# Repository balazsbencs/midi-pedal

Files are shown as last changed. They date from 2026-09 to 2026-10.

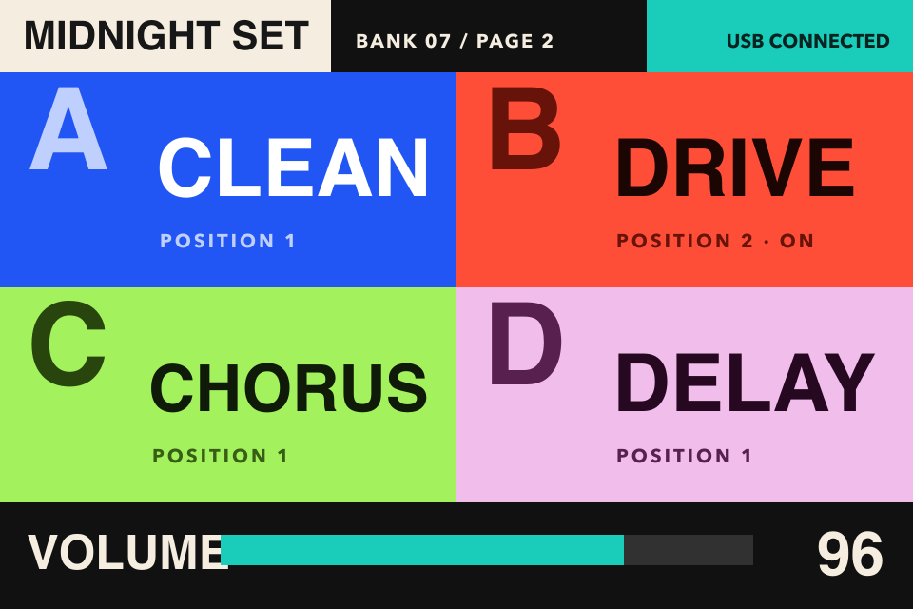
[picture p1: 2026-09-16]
docs/ui-concepts/05-gig-poster.png

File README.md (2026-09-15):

# MIDI Pedal

An open-source four-switch MIDI foot controller built around a Raspberry Pi Pico 2. It follows the focused live interaction model of the Morningstar MC4 Pro while keeping the hardware, protocol, and editor approachable for builders.

## Project status

This repository is work in progress. The approved design and implementation
roadmap are complete; firmware, editor, carrier PCB, enclosure files, and
qualification artifacts are being built in phases. Do not use an unqualified
revision on stage.

The v1 boundary is four normally-open footswitches, an ST7796S 480×320 display, TRS Type-A MIDI OUT, class-compliant USB-MIDI, one expression input, and two isolated normally-open relay contacts. There is no MIDI input, wireless feature, touch input, auxiliary control, USB host mode, or on-device setup menu.

## Start here

```bash
git clone --recurse-submodules git@github.com:balazsbencs/midi-pedal.git
cd midi-pedal
corepack enable
pnpm install --frozen-lockfile
pnpm check
```

Read the [approved design](docs/superpowers/specs/2026-09-01-midi-controller-pedal-design.md) and [implementation roadmap](docs/superpowers/plans/2026-09-01-midi-controller-pedal-implementation-plan.md) before building hardware.

The portable configuration and USB frame contracts are documented in [docs/protocol.md](docs/protocol.md). The phase plans define the exact firmware, editor, hardware, and release gates while implementation is in progress.

## Repository map

- `packages/protocol/` — shared JSON schema, binary image, and USB frame contracts.
- `firmware/` — Pico 2 C++20 firmware and native tests.
- `editor/` — static React editor for desktop Chromium browsers.
- `hardware/` — KiCad carrier PCB, enclosure drawings, and fabrication outputs.
- `docs/` — build, flashing, hosting, assembly, protocol, troubleshooting, and acceptance guides.
- `tools/` — validation, HIL, and release tooling.

Detailed guides: [building](docs/building.md), [flashing](docs/flashing.md), [editor hosting](docs/editor-hosting.md), [hardware assembly](docs/hardware-assembly.md), [protocol](docs/protocol.md), [troubleshooting](docs/troubleshooting.md), [releasing](docs/releasing.md), and [contributing](CONTRIBUTING.md).

## Build and flash

Use the verified [build guide](docs/building.md) and [flashing guide](docs/flashing.md). Power hardware only after reading the 9 V center-negative polarity and relay-contact warnings in the [assembly guide](docs/hardware-assembly.md).

The editor is available at
[balazsbencs.github.io/midi-pedal](https://balazsbencs.github.io/midi-pedal/)
and is automatically deployed from `main`; see
[editor hosting](docs/editor-hosting.md).
The browser connects directly to the pedal over WebSerial and never requires a
project account or backend. Configuration is intentionally prepared off-stage;
the pedal has no touch setup or wireless feature.

## Release downloads

Every push to `main` runs the release pipeline. It calculates the next SemVer
from conventional commits, builds the firmware, and publishes a GitHub Release
with the generated changelog, checksums, and downloadable `firmware.uf2` image.
Use the [GitHub Releases](https://github.com/balazsbencs/midi-pedal/releases)
page and follow the included `flashing.md` guide (or the checked-in
[flashing guide](docs/flashing.md)) before installing an image.

## License

The repository uses MIT for software, CERN-OHL-S-2.0 for hardware design, and
CC-BY-SA-4.0 for documentation. See [LICENSE](LICENSE) and the notices under
`LICENSES/` as they land.

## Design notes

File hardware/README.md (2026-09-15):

# Carrier hardware (work in progress)

The reference build uses a socketed Raspberry Pi Pico 2 on a two-layer carrier
inside a measured Hammond 1590DD-style enclosure. The electrical intent is
captured in the approved design specification and the bench-review sheets in
this directory. Production footprints and fabrication exports must not be
released until they have been checked against the actual display, jacks,
switches, relays, and enclosure.

Current repository artifacts:

- [`pico2-pinout.svg`](pico2-pinout.svg) is the illustrated firmware-to-panel
  wiring reference, including physical Pico 2 header pin numbers.
- `midi-pedal.kicad_pcb` is a safe board-outline/project starting point; it is
  not a routed production board.
- `bench/` contains review sheets for protected power and I/O circuits.
- `mechanical/measured-components.csv` records the measurements still needed
  before cutouts are frozen.
- `validation/` contains evidence tables; unchecked hardware rows are pending.

Never connect an unverified relay contact or external amplifier voltage to a
Pico GPIO. The two relay contacts must remain dry, isolated, and normally open.
Display logic is 3.3 V; verify a breakout's VCC rating before selecting its
3.3 V/5 V supply jumper. The ST7796S backlight is always on and SDO is not
routed.

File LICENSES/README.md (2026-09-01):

# License split

- `MIT.txt`: firmware, editor, protocol, tools, CI, and other software.
- `CERN-OHL-S-2.0.txt`: carrier PCB, schematics, footprints, fabrication, and
  enclosure/mechanical source.
- `CC-BY-SA-4.0.txt`: project documentation, plans, specifications, and
  validation guides.

Third-party code and documentation under `third_party/` retain their upstream
licenses. Each release manifest records the license for public artifacts.

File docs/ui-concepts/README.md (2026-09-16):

# Pedal display UI concepts

These five concepts use only information that the live firmware already exposes, except where noted. Every mockup is drawn at the display's native 480×320 aspect ratio and is intended to survive RGB565 conversion.

## 01 — Chromatic Deck (recommended)

The safest high-quality direction for a live pedal: a stable 2×2 spatial map matching switches A–D, with color used as a strong identity and a full fill for the active toggle state. It remains readable from standing distance and maps cleanly to dirty-region rendering.

Implementation: four fixed quadrant regions, a 42 px status header, and a 44 px expression footer. No new runtime state is required.

## 02 — Analog Console

A physical-instrument look based on rack labels, channel strips, indicator lamps, and a segmented expression meter. It feels like dedicated music hardware rather than a generic app.

Implementation: four fixed columns. Circles and meter segments are simple integer primitives. No image assets or new runtime state are required.

## 03 — Performance Focus

The most recently operated switch becomes the hero while the other three remain visible in a side rail. This has the strongest active-state feedback and the largest preset name.

Implementation: requires adding `activeSwitch` to `LiveView`, updated on switch activation. A switch change redraws the hero and side rail, so it moves more pixels than the fixed-grid concepts.

## 04 — Signal Flow

A vertical chain view that reads like a signal path. The selected preset is a full-width interruption in the chain; inactive choices are quieter but still clear.

Implementation: four horizontal rows and fixed state badges. It uses only current runtime data and makes each row independently redrawable.

## 05 — Gig Poster

The boldest direction: borderless color fields and oversized condensed type. It treats the display like stage graphics, with almost no interface chrome.

Implementation: four fixed quadrant fills plus a footer. This is computationally the simplest concept and has the best fallback behavior if typography is reduced to a 1-bit mask.

## Rendering plan

- Keep the current 480×320 RGB565 framebuffer: 307,200 bytes.
- Store font glyph atlases in flash, not RAM. Convert an open-source condensed display face and a highly legible small face into 4-bit alpha masks at build time. Blend those masks directly into RGB565; this gives visibly smoother type without LVGL.
- Add a small renderer layer for filled rectangles, lines, circles, clipped text, and alpha-mask glyphs. These five concepts need no general widget framework.
- Draw into the existing framebuffer and use the panel's proven full-screen address window. This specific module misplaces partial vertical windows, so correctness takes priority over regional transfer size.
- Hold chip-select active for the frame and stream it four scanlines at a time. MIDI, USB, switch scanning, and watchdog work run between these bounded transfer steps while the controller remains in continuous RAM-write mode.
- At the current 8 MHz SPI clock, a full frame takes about 307 ms of total wire time, but no individual display service step blocks the control loop for more than roughly four scanlines. A future optimization can retest higher SPI clocks on the real unit in measured steps.
- Keep state readable without color: active presets also receive a solid fill plus an explicit `ON` or `ACTIVE` label.
- Avoid continuous decorative animation at 8 MHz. State changes and the expression meter update incrementally without blocking the control loop for a complete frame.

## Font direction

Use a condensed, wide-aperture face for preset names and large switch letters, paired with a very legible regular-width face for status text. The production font set only needs uppercase letters, digits, basic punctuation, and the characters accepted by the configuration format, keeping flash cost controlled.

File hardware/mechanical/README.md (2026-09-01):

# Mechanical files

The DXF and SVG files are reference templates at nominal Hammond 1590DD
dimensions only. Connector and footswitch cutouts are intentionally absent
until `measured-components.csv` contains measurements from the supplied parts.
Print `drill-template.svg` at 100% on a 1:1 sheet, overlay the actual enclosure
and hardware, and record any change before producing metal or STEP/PDF exports.

STEP assembly and dimensioned PDF are release deliverables, not claims about
the current placeholder outline.

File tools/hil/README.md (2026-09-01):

# Hardware-in-the-loop runner

`@midi-pedal/hil` records machine-readable evidence without pretending that a
simulator proves electrical safety. The default release suite deliberately
marks hardware-dependent cases as `SKIP` with a reason; because those cases are
release-blocking, the overall report is `FAIL` until a real rig supplies
captures and signed manual measurements.

Run the deterministic simulated report with:

```bash
pnpm --filter @midi-pedal/hil test
pnpm hil:release -- --rig simulated --report build/hil-simulated.json
```

Adapters for CDC configuration, MIDI capture, and safe manual prompts are
separate from the report schema. Attach raw captures and the firmware/editor
commit to any report used for release qualification.

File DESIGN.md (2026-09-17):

---
name: MIDI Pedal — Chromatic Deck
description: A saturated, glanceable stage interface built around the physical A–D switch map.
colors:
  stage-black: "#071013"
  status-surface: "#0D1A1F"
  deck-surface: "#102229"
  deck-white: "#F2FAFB"
  muted-steel: "#6F8289"
  signal-cyan: "#2BE5D2"
  hot-coral: "#F25F5C"
  ultraviolet: "#C99BFF"
  cue-yellow: "#FFCB47"
  connected-green: "#4DF7A4"
typography:
  display:
    fontFamily: "Barlow Condensed, sans-serif"
    fontSize: "30px"
    fontWeight: 700
    lineHeight: 1
    letterSpacing: "normal"
  status:
    fontFamily: "Atkinson Hyperlegible, sans-serif"
    fontSize: "11px"
    fontWeight: 700
    lineHeight: 1.1
    letterSpacing: "0.08em"
rounded:
  deck: "10px"
  indicator: "3px"
spacing:
  xs: "4px"
  sm: "8px"
  md: "16px"
components:
  preset-inactive:
    backgroundColor: "{colors.deck-surface}"
    textColor: "{colors.deck-white}"
    typography: "{typography.display}"
    rounded: "{rounded.deck}"
    padding: "16px"
  preset-active:
    backgroundColor: "{colors.hot-coral}"
    textColor: "{colors.stage-black}"
    typography: "{typography.display}"
    rounded: "{rounded.deck}"
    padding: "16px"
---

# Design System: MIDI Pedal — Chromatic Deck

## Overview

**Creative North Star: "Chromatic Deck"**

The display behaves like a compact stage instrument: four stable performance surfaces mirror the four physical switches, while preset color turns the entire screen into a memorable map. The interface is energetic but never ornamental; every large color field communicates identity or state.

The operating scene is a musician standing above a pedalboard under inconsistent stage light. Large condensed names, fixed positions, and redundant active-state cues take priority over density.

**Key Characteristics:**

- Saturated color fields anchored by a near-black stage surface.
- Stable 2×2 A–D spatial mapping.
- Condensed display type paired with unmistakable status text.
- Flat tonal layers with no shadows or simulated glass.

## Colors

The palette combines deep blue-black structural surfaces with user-configurable preset colors. Cyan is the system accent; coral, ultraviolet, and yellow demonstrate the intended chromatic range.

**The Full-Field State Rule.** Inactive presets use a narrow color rail; position 2 fills the complete tile and adds explicit state text.

**The Functional Color Rule.** Every color field carries preset identity, toggle state, connection status, or diagnostics. Decoration alone does not earn color.

## Typography

**Display Font:** Barlow Condensed Bold, converted to a flash-resident glyph atlas.

**Status Font:** Atkinson Hyperlegible Bold, converted to a flash-resident glyph atlas.

Large preset names are compact and assertive. Small status labels prioritize character distinction and remain readable from off-axis viewing angles.

**The Distance Test.** Switch letter, preset name, and active state must remain identifiable before bank/page details become readable.

## Layout

The live display uses a 480×320 fixed canvas: a compact status header, a 2×2 deck aligned with switches A–D, and a persistent expression footer. The four preset regions never reorder. Diagnostics temporarily replace the right side of the status header rather than shifting the deck.

## Elevation & Depth

The system is entirely flat. Depth comes from large changes in surface tone and state fill, not shadows, gradients, or transparency.

## Shapes

Preset surfaces use a confident 10 px radius. Color rails and expression tracks use small 3 px radii. Text and indicators align to an 8 px spacing rhythm.

## Components

### Preset Tile

Inactive tiles use the deck surface, a six-pixel preset-color rail, white name, muted state label, and colored switch letter. Active tiles become a full preset-color field with automatically selected light or dark foreground and an explicit `ON` label.

### Status Header

Bank number is subordinate to bank name. Page and USB state occupy the right edge. A connected dot accompanies text so connection is never color-only.

### Expression Footer

The assignment name and numeric value bracket one long horizontal meter. The meter uses the system cyan rather than the selected preset color.

## Do's and Don'ts

### Do:

- **Do** keep A, B, C, and D anchored to their physical switch positions.
- **Do** make active state legible through fill, wording, and contrast together.
- **Do** clip or abbreviate labels predictably instead of shrinking them below the distance threshold.

### Don't:

- **Don't** add shadows, glass effects, decorative gradients, or faux hardware texture.
- **Don't** animate continuously or make MIDI handling wait on display effects.
- **Don't** use color as the only indication of toggle, USB, warning, or error state.

---

## Browser Editor: Studio Console

The browser editor is the desk-side companion to Chromatic Deck. Its dark theme is a faithful studio-console expression of the live surface: a full-width command bar, persistent bank rail, dominant 2×2 switch deck, and tall inspector rendered in the same saturated functional palette.

### Editor composition

- The command bar spans the complete app frame: product lockup at left, device and file actions at right.
- The bank rail begins below the command bar and keeps search plus the numbered bank list visible.
- The A–D map is the visual center of gravity. Each switch becomes a large near-square field with a vivid cyan, coral, violet, or yellow identity, oversized letter, and compact label.
- Preset settings, ordered messages, and expression settings live in one right-hand inspector with clear section boundaries.
- The inspector favors progressive disclosure: disabled subsystems collapse to a status line, message rows show a compact summary until opened, and primary preset controls remain visible without scrolling at laptop height.
- At narrower widths the inspector moves below the map; on phones all regions become one readable vertical flow.

### Editor material and type

- The dark editor uses Stage Black, Signal Cyan, Hot Coral, Ultraviolet, Cue Yellow, and Connected Green directly. Light mode remains available as an accessible alternative.
- Saved preset colors remain authoritative. Empty factory presets use the four canonical A–D colors so the editor still communicates the physical layout before configuration.
- Use a neutral modern sans-serif stack with compact weights and tabular numbers. Headings are clear rather than oversized.
- Surfaces use restrained 10–14 px radii, crisp one-pixel borders, and shallow shadows only where they separate the application frame from the canvas.
- Controls are 38–42 px tall, labels remain visible, and focus rings are never removed.

### Editor interaction rules

- Selected states combine outline, surface change, and explicit text or `aria-current`.
- Connection, validation, and sync status are persistent and never color-only.
- Hover and press motion is brief and limited to direct manipulation; reduced-motion preferences remove it.
- File, device, and editing behavior must remain available at every supported breakpoint.

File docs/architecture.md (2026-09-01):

# Architecture overview

The product has four independently testable boundaries:

1. `packages/protocol` owns the JSON schema, deterministic binary image, CRC,
   and USB frame contracts shared by TypeScript and C++.
2. `firmware/src/core` is hardware-independent C++20. It recognizes gestures,
   executes ordered actions, filters expression, and atomically selects flash
   images without dynamic allocation in the live path.
3. `firmware/src/hal`, `firmware/src/usb`, and `firmware/src/display` adapt Pico
   GPIO/UART/ADC/flash, TinyUSB, and the write-only ST7796S SPI panel. The
   `PicoUsbPort` keeps CDC responses bounded and non-blocking, while the
   `ProtocolDispatcher` routes every framed editor command to the flash-backed
   `ControllerProtocolService`.
4. `firmware/src/app/pedal_runtime.cpp` is the live-loop coordinator. It loads
   the selected bank, feeds switches and expression samples into the core,
   routes TRS/USB MIDI and relay commands, applies navigation, and submits
   dirty-only `LiveView` updates to the display.
5. `editor` is a static Chromium application. Its reducer keeps drafts local;
   `DeviceSession` sends framed whole-image synchronization over WebSerial.

The carrier hardware is deliberately a separate measured layer. Relay contact
isolation, power source handover, and display-module voltage are not inferred
from software tests. See the approved [design specification](superpowers/specs/2026-09-01-midi-controller-pedal-design.md)
for fixed pin/timing/safety decisions.

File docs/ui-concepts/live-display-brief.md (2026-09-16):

# Live display surface brief

- Mode: operate. A musician standing above the pedalboard must identify bank, four switch assignments, active toggle states, and expression status at a glance.
- Direction: Chromatic Deck. The stable 2×2 deck mirrors A–D; inactive presets carry a narrow identity rail, while position 2 becomes a full color field with explicit `ON` wording.
- Memorable moment: pressing a toggle turns its entire tile into the preset color without moving any content.
- Constraints: 480×320 ST7796S, RGB565, Pico 2, four switches, no touch, deterministic MIDI path, flash-resident fonts, and region-based redraws.
- Scope: live screen only. Configuration remains in the browser editor. Continuous animation, decorative imagery, and a generalized widget framework are out of scope.

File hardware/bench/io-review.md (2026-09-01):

# I/O bench review sheet

Before carrier integration, draw and review these measured circuits on the
bench sheet:

- MIDI OUT: standards-representative 3.3 V current-loop driver and Type-A TRS
  mapping; no external jack conductor directly reaches a GPIO.
- Relay: two independent mechanical dry contacts, transistor drivers,
  flyback diodes, and default-off pull components. Tip and ring switch to
  sleeve independently and remain isolated from logic.
- Expression: protected 3V3 ring, tip through the RC/protection network to
  ADC0/GP26, sleeve ground; voltage-divider pedals only.
- Switches: four normally-open contacts to ground with pull-ups and GPIO
  protection.
- Display: nine-position header matching `GND,VCC,SCL,SDA,RST,DC,CS,BL,SDA-0`;
  SDO/SDA-0 is no-connect, BL is tied on, and logic is 3.3 V.

ERC, pin-order review, and component identities are pending.

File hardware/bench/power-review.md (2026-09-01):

# Protected power bench review sheet

The KiCad sheet is a project placeholder until the selected regulator,
reverse-polarity stage, fuse, TVS, and source-isolation parts are measured and
entered. The intended topology is:

```text
USB VBUS ── reverse-current isolation ─┐
                                       ├── VSYS ── Pico 2
9 V center-negative ─ fuse ─ TVS ─ buck ┘
```

Required test points: raw 9 V, protected input, regulated 5 V, USB VBUS, VSYS,
3V3, and GND. The assembled circuit must not backfeed USB or the DC jack,
must survive source handover, and must be tested with a current-limited supply
before a Pico is fitted. Part selection and ERC are pending independent review.

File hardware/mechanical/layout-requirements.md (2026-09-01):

# Mechanical layout requirements

These are design constraints, not a claim that the current outline has passed
fit checking.

- Display above the switch field in landscape orientation; visible screen is
  480×320 and the panel header is on the rear/inside edge.
- Footswitch order is A/B on the top row and C/D on the bottom row, matching
  the firmware chord map and editor map.
- Keep at least 15 mm between footswitch nut envelopes and neighboring
  hardware. Verify with the actual shoes/cables before drilling metal.
- Keep the Pico USB connector accessible without opening the enclosure.
- Keep MIDI, relay, expression, and DC jacks reachable with right-angle plugs
  and their specified cable bend radius.
- Leave SWD/debug access and Pico socket removal clearance.
- No unsleeved conductor may touch the aluminum lid or an enclosure edge.
- Display module VCC selection is a documented assembly option; logic remains
  3.3 V, BL is hardwired on, and SDO is intentionally no-connect.

Second-review sign-off: __________________  Date: __________

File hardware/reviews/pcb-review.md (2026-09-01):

# PCB review

Status: **not reviewed**. The current board is an outline/project starting
point, not a fabrication release.

- [ ] Measured footprints and courtyards checked at 1:1
- [ ] Pico USB and SWD access remain serviceable
- [ ] Protection/regulator loops are compact and thermally appropriate
- [ ] Relay contact copper is isolated from controller logic
- [ ] ADC and SPI routes have continuous return paths and noise separation
- [ ] Connector labels, polarity, pin 1, and panel cable direction are clear
- [ ] ERC and DRC completed with no blanket exclusions
- [ ] Gerber/drill/BOM/placement hashes recorded

Reviewer: __________________  Date: __________  Revision: __________

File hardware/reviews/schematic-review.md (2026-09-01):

# Schematic review

Status: **not reviewed**. Complete this checklist after replacing the bench
placeholders with measured symbols and parts.

- [ ] USB/9 V source direction and reverse-current isolation
- [ ] 9 V polarity, fuse, TVS, regulator ratings
- [ ] Pico pin mux matches `firmware/src/board/pico2_pins.hpp`
- [ ] MIDI Type-A polarity/current-loop protection
- [ ] Relay coil drivers, flyback, pull defaults, and contact isolation
- [ ] Expression ADC protection, RC, and TRS pin meaning
- [ ] Display header order, VCC selection, BL tie-on, and SDO no-connect
- [ ] Connector numbering and fabrication labels
- [ ] ERC clean with each intentional exception documented

Reviewer: __________________  Date: __________  Revision: __________

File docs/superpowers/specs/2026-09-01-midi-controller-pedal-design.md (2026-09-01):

# MIDI Controller Pedal Design Specification

**Status:** Approved for implementation planning
**Date:** 2026-09-01
**Reference product:** Morningstar MC4 Pro interaction model

## 1. Product intent

Build an approachable open-source four-switch MIDI controller around a Raspberry Pi Pico 2 development board. The controller should deliver the core live experience of the Morningstar MC4 Pro while remaining deliberately smaller in scope and easier to understand, assemble, repair, and modify.

The product has two operating contexts:

- **On stage:** it runs without a computer, uses a standard pedalboard power supply, and prioritizes deterministic switch-to-output behavior.
- **On a desk:** one USB cable can power it, configure it from a Chromium browser, and carry class-compliant USB-MIDI.

The editor is a static browser application. It communicates directly with the pedal and never requires an account, cloud database, network connection, or server-side device access.

## 2. Goals and non-goals

### Goals

- Four programmable footswitches with an MC4-style bank/page workflow.
- Clear 480×320 live feedback that spatially mirrors the four switches.
- TRS Type-A MIDI OUT and class-compliant USB-MIDI.
- Per-message routing to TRS, USB, or both.
- One calibrated expression-pedal input.
- Two independent normally-open dry-contact relay outputs on one TRS jack.
- Safe USB and 9 V center-negative power operation.
- A documented, human-readable backup format and open device protocol.
- Atomic configuration updates with recovery from interrupted or corrupt uploads.
- Hardware and software that open-source builders can understand without specialized manufacturing equipment.

### Non-goals for v1

- MIDI input or MIDI message conversion.
- Wi-Fi, Bluetooth, or any future-facing wireless abstraction.
- On-device editing, setup menus, or touch input.
- Auxiliary switch inputs or configurable Omniports.
- USB host mode.
- MIDI Note, Clock, SysEx, MMC, keystrokes, or arbitrary delayed macros.
- More than one expression input or one relay TRS port.
- Cloud accounts, synchronization, telemetry, or hosted configuration storage.
- Safari, Firefox, or mobile-browser support.

## 3. Product architecture

The system has a strict boundary between configuration and live execution.

### Browser side

The hosted static editor:

- Reads a device descriptor and active configuration over USB CDC/WebSerial.
- Maintains edits as a local draft.
- Validates the complete draft before synchronization.
- Compiles portable JSON into the versioned device binary format.
- Uploads, verifies, and activates a complete configuration image.
- Imports and exports configuration as local JSON files.
- Exposes no backend API and transmits no configuration off the computer.

### Pedal side

The Pico 2 firmware:

- Uses C++ with the Raspberry Pi Pico SDK and TinyUSB, without an RTOS in v1.
- Runs the live engine and non-blocking services on one core; the second core remains unused unless measurement proves it necessary.
- Owns footswitch timing, chord recognition, toggle state, expression processing, output routing, and display state.
- Executes only a previously validated configuration image.
- Keeps USB configuration parsing, flash writes, and display transfers out of the time-sensitive switch-to-MIDI path.
- Uses bounded queues and non-blocking services for TRS MIDI, USB-MIDI, and display updates.

### Architectural invariant

Editing, serialization, flash writes, and display drawing must not delay or reorder live actions. A USB disconnect or editor failure must not interfere with TRS MIDI or relay behavior.

## 4. Hardware design

### Controller and carrier

- Use a non-wireless Raspberry Pi Pico 2 development board mounted on headers or sockets to a two-layer carrier PCB.
- Keep the Pico USB connector accessible through the enclosure.
- Use the Pico's native USB device controller; USB does not consume general-purpose GPIO.
- Reserve unused pins and SWD access for debugging and future board revisions, without assigning them future product features.

The estimated active GPIO budget is 13 pins: five display, four footswitch, two relay control, one expression ADC, and one UART TX.

The reference mechanical build uses a drilled aluminum stompbox enclosure with the display above the 2×2 switch field. MIDI, relay, expression, 9 V, and USB connections remain accessible without opening the enclosure. Exact enclosure and cutout dimensions are derived from measured production modules during the mechanical prototype; they do not alter the electrical interfaces in this specification.

### Display

- Controller: ST7796S, 480×320, landscape orientation.
- Interface: write-only four-wire SPI using SCL, SDA/MOSI, CS, DC, and RST.
- SDO/MISO remains unconnected.
- Backlight is permanently enabled and has no firmware brightness setting.
- Display logic is always 3.3 V.
- A documented solder selection supplies either 3.3 V or 5 V module power because breakout boards vary; the selected module voltage must be verified before assembly.
- Rendering uses dirty rectangles and small DMA buffers rather than a full-screen RGB565 framebuffer.

### Footswitches

- Four normally-open momentary footswitches named A, B, C, and D.
- Each input uses a protected GPIO with a defined pull state.
- Firmware performs debounce and all higher-level gesture recognition.
- There are no encoders, menu buttons, or setup controls.

### Expression input

- One 6.35 mm TRS jack supporting voltage-divider expression pedals only.
- Target pedal potentiometer range: 10–25 kΩ linear.
- Ring provides a protected 3.3 V reference, tip is the wiper/ADC input, and sleeve is ground.
- The ADC path includes input protection and an RC low-pass filter.
- Heel and toe ADC readings are calibrated once for the physical input and stored as controller-level settings, not repeated per bank.
- TS rheostat wiring is not supported.

### Relay output

- One 3.5 mm TRS relay jack.
- Contact 1 switches tip to sleeve; contact 2 switches ring to sleeve.
- Use two independently driven mechanical dry-contact relays.
- Both contacts are normally open and electrically isolated from controller logic.
- Reset, brownout, watchdog, and unpowered states leave both contacts open.
- Firmware supports explicit open, close, and toggle commands. Momentary behavior is composed from close-on-press and open-on-release actions.

### MIDI output

- One 3.5 mm TRS Type-A MIDI OUT.
- Drive it from a hardware UART through a standards-compliant, current-limited output stage; do not connect the jack directly to a GPIO.
- USB enumerates as a class-compliant USB-MIDI output in addition to the configuration interface.
- Each PC or CC message selects `TRS`, `USB`, or `BOTH`; the editor defaults new messages to `BOTH`.

### Power

- Accept USB 5 V or 9 V center-negative DC.
- Protect the 9 V input against reverse polarity, overcurrent, and transients.
- Convert the protected 9 V rail to the board's 5 V system rail with an efficient regulator.
- Combine USB and regulated pedal power without backfeeding either source.
- Removing either source while the other is present must not reset the controller.

## 5. Live interaction model

### Navigation

Use the MC4 Pro chord map exactly:

- A+C: bank down.
- B+D: bank up.
- A+B: page down.
- C+D: page up.
- Holding a chord repeats its navigation action.

Recognized chords suppress all constituent preset events. There is no four-switch setup chord.

### Timing constants

The following are fixed firmware constants in v1 and are not editor settings:

- Debounce stability: 20 ms.
- Chord-recognition window: 35 ms from the first physical edge; debounce occurs within this window.
- Double-tap window: 300 ms from the first recognized press.
- Long-press threshold: 500 ms from the recognized press.
- Navigation repeat delay: 600 ms.
- Navigation repeat interval: 200 ms.

A normal press fires after the chord window. A double tap also produces the ordinary press events for its two constituent taps; the double-tap event is additional. A long press also follows the initial press event. These semantics avoid delaying normal press actions for 300–500 ms.

### Toggle semantics

- Each preset has Position 1 and Position 2.
- A preset may toggle after press, long press, double tap, or not toggle.
- Messages matching the trigger execute against the current position in their configured order.
- The position transition occurs only after all matching messages have been queued.
- Toggle positions survive page and bank changes during the power session.
- All positions reset to Position 1 on boot.

## 6. Configuration model

### Capacity

- 128 banks.
- Four pages per bank.
- Four switch presets per page.
- Up to eight ordered message slots per preset.
- One expression assignment per bank.

### Bank and preset presentation

- Bank names contain at most 20 printable ASCII characters in v1.
- Each toggle position has a label of at most 12 printable ASCII characters and one RGB565 accent color.
- The device uses a fixed high-contrast dark screen theme; browser Light/Dark mode does not affect it.
- Unsupported or corrupt strings are rejected during validation rather than silently truncated.

### Message slot

Each slot contains:

- Trigger: `PRESS`, `RELEASE`, `LONG_PRESS`, or `DOUBLE_TAP`.
- Position filter: `POSITION_1`, `POSITION_2`, or `BOTH`.
- Message type and its validated parameters.

Supported v1 message types are:

- Program Change: channel 1–16, program 0–127, destination TRS/USB/both.
- Control Change: channel 1–16, controller 0–127, value 0–127, destination TRS/USB/both.
- Relay command: contact 1 or 2, operation open/close/toggle.
- Internal navigation: bank up/down/set 1–128 or page up/down/set 1–4.

All matching messages are queued in slot order without programmable delays.

### Expression assignment

Each bank defines:

- Enabled/disabled.
- Display label of at most 12 printable ASCII characters.
- MIDI channel and CC number.
- Destination TRS, USB, or both.
- Output minimum and maximum, each 0–127.
- Normal or inverted direction.

Firmware samples the ADC at 1 kHz, applies a five-sample median followed by a first-order IIR filter with coefficient 0.2, maps the result through the global calibration, and applies one MIDI-value step of hysteresis. It sends only changed mapped values and sends no faster than once every 20 ms. An absent pedal or calibration span below 10% of ADC range produces no MIDI and displays expression as unavailable.

## 7. Storage and transport

### Portable JSON

- JSON is the documented backup, interchange, and source-control format.
- It contains an explicit schema version and stable identifiers for banks, pages, presets, and messages.
- The editor preserves unknown top-level metadata when it can do so safely, but rejects unsupported behavioral fields.

### Device image

- The editor compiles JSON into a compact, documented binary image.
- The image has a magic value, format version, total length, sequence number, bank-offset index, payload, and checksum.
- Firmware reads only the current bank into working RAM; toggle state for all presets remains a compact RAM bitset.

### Atomic synchronization

- Flash reserves active and inactive configuration slots.
- The current active slot remains readable throughout upload.
- Firmware writes the inactive slot, validates its complete structure and checksum, reads it back, and only then updates the active-slot marker.
- Power loss, cable removal, malformed input, or checksum failure leaves the active configuration unchanged.
- Boot chooses the newest valid active slot, falls back to the other valid slot, then falls back to a safe empty factory configuration.

### USB protocol

- USB is a composite device with class-compliant MIDI and CDC configuration interfaces.
- Configuration traffic uses framed requests and responses with protocol version, request identifier, command, payload length, payload, and checksum.
- Commands cover capability/version query, configuration metadata, download, staged upload, verification, activation, expression calibration, and factory-empty reset.
- Every mutating command returns a structured success or error response; retrying a request identifier is idempotent.

## 8. Device display

The 480×320 screen is landscape and live-performance-only:

- Header: bank name on the left; bank number and page number on the right.
- Center: four equal quadrants laid out A top-left, B top-right, C bottom-left, and D bottom-right.
- Each quadrant shows the current-position label, switch letter, toggle position, and accent color. Text or symbols also communicate state so color is never the only indicator.
- Footer: expression assignment name/CC, value bar, and numeric value; show an unavailable marker when disconnected or invalid.

The screen displays brief non-modal indicators for USB connection, configuration activation, and recoverable errors. It has no settings or editing screens.

## 9. Browser editor experience

### Supported environment

- Static web application hosted on any ordinary HTTPS server.
- Desktop Chrome, Edge, and Brave are supported in v1.
- Direct connection uses WebSerial with an explicit browser permission prompt.

### Workspace structure

- Top bar: device connection/status, theme, unsynced-change status, Export JSON, Import JSON, and Sync to pedal.
- Left pane: searchable 128-bank list.
- Center pane: page tabs, a 2×2 pedal-shaped preset map, and the bank expression assignment.
- Right pane: selected preset metadata, Position 1/2 presentation, toggle trigger, and ordered message editor.
- Bottom status: validation outcome and whether the draft matches the pedal.

The four center cards mirror the physical screen and switch positions. Selecting a bank, page, preset, or position changes editor context; it does not write to the pedal.

### Synchronization model

- Connecting reads device capabilities, versions, active-image metadata, and configuration.
- Edits create an explicit dirty local draft.
- Sync is disabled while validation fails.
- Sync uploads the whole compiled image atomically and verifies the activated checksum before reporting success.
- Navigating away with unsynced changes requires confirmation.
- Import previews schema/version and validation results before replacing the draft.
- Export always writes the current local draft, including unsynced changes, to JSON.

### Light and Dark modes

- Provide an explicit, keyboard-accessible Light/Dark switch in the top bar.
- On first visit, initialize from `prefers-color-scheme`.
- After the user chooses a mode, persist it locally and give it precedence over later operating-system changes.
- Implement both modes from shared semantic tokens.
- Both modes must maintain WCAG AA contrast for text, controls, validation, connection state, and visible focus.

### Required editor states

- No device selected.
- Browser permission denied, with recovery instructions.
- Connected and synchronized.
- Connected with unsynced draft changes.
- Draft validation errors linked to their fields.
- Uploading and verifying, with controls that would invalidate the operation disabled.
- Verification or activation failure, with the previous pedal configuration explicitly reported as intact.
- Firmware/protocol or configuration-schema incompatibility.
- Unexpected USB disconnect, preserving the local draft.

## 10. Fault handling and safety

- Invalid or missing flash configuration never prevents USB configuration access.
- TRS MIDI continues if the USB host is absent or disconnects.
- USB-destined messages are dropped when unavailable; they never block other destinations.
- TRS and USB each have a bounded 64-message MIDI queue. Overflow sets a visible diagnostic and drops the newest message for the affected output without corrupting messages already queued.
- Invalid expression calibration or a disconnected pedal sends no expression MIDI.
- Relay drivers use electrical defaults that keep both contacts open before firmware initialization.
- Watchdog recovery returns to the last valid configuration and Position 1 states.
- Flash writes happen only during explicit editor synchronization or reset, never during live switch, relay, or expression activity.

## 11. Verification strategy

### Firmware unit and integration tests

- Debounce and exact timing boundaries.
- All four chords, constituent-event suppression, and held repeat.
- Press, release, long-press, and double-tap interactions.
- Toggle transition ordering and session persistence.
- Ordered PC, CC, relay, and navigation messages.
- Expression calibration, inversion, filtering, hysteresis, and rate limiting.
- Binary-image validation, slot selection, corrupt images, and interrupted activation.
- Queue overflow and unavailable-output behavior.

### Shared contract tests

- Store golden JSON files and their expected binary images in a language-neutral fixture directory.
- Run the same valid, boundary, and invalid fixtures through the editor encoder and firmware decoder.
- Verify protocol framing, request idempotency, error codes, and schema/version negotiation.

### Editor tests

- Draft editing, validation, import/export, dirty-state protection, and full synchronization states.
- Simulated transport for disconnects, timeouts, corrupt reads, unsupported versions, and activation failure.
- Keyboard operation, focus order, zoom, long labels, and Light/Dark contrast.
- Chromium integration tests using a real or loopback WebSerial transport where automation permits.

### Hardware-in-the-loop tests

- Capture and compare TRS MIDI bytes and USB-MIDI packets.
- Measure press-to-MIDI timing and output ordering.
- Exercise all relay open/close/toggle transitions and confirm fail-open behavior during reset and power loss.
- Sweep valid expression pedals and test unplugging, endpoint noise, and invalid calibration spans.
- Run from USB only, 9 V only, and both; remove either source while the other remains.
- Interrupt configuration upload at multiple offsets and verify the old configuration remains active.
- Capture display snapshots for both toggle positions, every quadrant, expression unavailable, long labels, and error indicators.

### Acceptance criteria

- No lost or reordered messages while neither 64-message output queue is full.
- Normal press-to-MIDI output completes within 50 ms of the initial physical edge, including chord recognition.
- Visible display feedback begins within 100 ms of an accepted action.
- The inactive configuration slot cannot become active without full validation and readback.
- Both relay contacts remain open throughout boot, reset, watchdog recovery, brownout, and unpowered states.
- Removing USB or 9 V while the other source is already present does not reset the controller.
- The editor remains fully usable with keyboard input and at 200% browser zoom on a typical laptop viewport.

## 12. Architecture decision record

### Pico 2 rather than ESP32-S3

Pico 2 was selected because it provides sufficient GPIO, RAM, flash, DMA, ADC, UART, SPI, and native USB without adding an unused radio subsystem. Its development-board form also makes the open-source reference build easier to assemble and replace. ESP32-S3 remains technically capable but offers no required v1 advantage that outweighs its extra platform and RTOS complexity.

### Carrier PCB before an integrated RP2350 board

The first hardware revision uses the standard Pico 2 to reduce board bring-up risk and improve reproducibility. Interfaces and firmware boundaries must avoid assumptions that prevent a later integrated RP2350 board, but that later board is not part of v1.

### Compact device image plus JSON interchange

Human-readable JSON makes backup, review, and community sharing approachable. A compiled binary image keeps boot validation and random bank access deterministic without requiring the firmware to parse and retain the complete JSON document.

### Explicit synchronization rather than live writes

The editor maintains a draft and writes a complete atomic image only on request. This makes configuration state understandable, minimizes flash wear, and prevents a partially edited preset from becoming active on stage.

## 13. Implementation-planning boundary

This specification describes one product, but implementation must proceed through independently verifiable stages rather than attempting the complete system at once:

1. Shared configuration schema, binary image, protocol, and golden fixtures.
2. Bench electronics and Pico 2 hardware-interface proofs.
3. Deterministic firmware engine, persistence, USB composite device, and display.
4. Static browser editor against a simulated transport, followed by real-device integration.
5. Carrier PCB, power validation, enclosure, hardware-in-the-loop qualification, and release documentation.

Each stage must meet its own tests before the next stage depends on it. The implementation plan may subdivide these stages, but it must not merge their verification gates.

## 14. Source references

- [Morningstar MC4 Pro User Manual](https://help.morningstar.io/en/article/mc4-pro-user-manual-1p5o2cp/): reference for the four-switch bank/page interaction, presets, actions, toggle positions, expression behavior, and relay concepts.
- [Raspberry Pi Pico 2 documentation](https://www.raspberrypi.com/documentation/microcontrollers/raspberry-pi-pico.htmlPICO): RP2350 board capabilities, memory, GPIO, ADC, and USB support.
- [Raspberry Pi Pico C/C++ SDK](https://datasheets.raspberrypi.com/pico/raspberry-pi-pico-c-sdk.pdf): native SDK and TinyUSB device support.
- [ESP32-S3 USB Device Stack](https://docs.espressif.com/projects/esp-usb/en/latest/esp32s3/usb_device.html): alternative-platform composite USB capabilities considered during selection.

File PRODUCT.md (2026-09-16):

# Product

<!-- impeccable:product-schema 1 -->

## Platform

web

## Stack

Static React 19.2 application built with TypeScript 5.9 and Vite 8, tested with Vitest and Playwright Chromium, and deployable to an ordinary HTTPS host without a backend. Firmware uses C++20 with Raspberry Pi Pico SDK 2.2.0 and TinyUSB; carrier hardware is authored in KiCad 10.0.6.

## Users

Musicians and open-source hardware builders who want an approachable, programmable four-switch MIDI foot controller for pedalboards, desktop rigs, DAWs, and plugins. Builders should be able to understand, assemble, repair, and modify the reference design around a readily available Raspberry Pi Pico 2 development board.

## Product Purpose

Provide the core live experience of a Morningstar MC4 Pro-style controller without its broader feature set: four programmable switches, bank and page navigation, clear live feedback, physical and USB MIDI output, expression control, and two dry-contact relay outputs. Configuration happens off-stage through a directly connected browser editor.

Success means reliable, low-latency live operation; configuration that a musician can understand without reading firmware code; and hardware that open-source builders can reproduce without specialized assembly.

## Positioning

The project pairs a deliberately focused live controller with a transparent, documented configuration model and a module-based reference build. It favors understandable behavior and repairability over feature-count competition.

## Operating Context

- On stage, the controller runs independently from a computer and is powered by a standard 9 V center-negative pedal supply.
- On a desk, USB can power the controller, configure it from a Chromium browser, and carry class-compliant USB-MIDI.
- The editor is hosted as static files and communicates directly with the controller. It has no accounts, cloud storage, analytics, or server-side device access.
- Portable configuration backups are local, human-readable JSON files.

## Capabilities and Constraints

- Raspberry Pi Pico 2 reference controller; wireless hardware and software are out of scope.
- Four footswitches and no additional physical controls or touch input.
- ST7796S 480×320 SPI display with an always-on backlight and a live-performance-only interface.
- Exact MC4 Pro navigation chords: A+C bank down, B+D bank up, A+B page down, and C+D page up, with hold-to-repeat.
- 128 banks, four pages per bank, four presets per page, two toggle states, and up to eight ordered messages per preset.
- Program Change, Control Change, relay control, internal navigation, press, release, long-press, and double-tap are the v1 action scope.
- One TRS voltage-divider expression input with calibration and filtering.
- One 3.5 mm TRS Type-A MIDI output and class-compliant USB-MIDI, selectable per message.
- One 3.5 mm TRS relay connector with two independent, normally-open dry contacts.
- USB or protected 9 V center-negative power.
- Configuration is editor-only. The controller has no setup menu.
- Desktop Chromium-family browsers are the supported editor environment for v1.
- The editor provides explicit Light and Dark modes. The first visit opens in the dark Studio Console theme; an explicit user choice is stored locally and takes precedence afterward.

## Evidence on Hand

- Morningstar MC4 Pro user manual is the interaction reference: https://help.morningstar.io/en/article/mc4-pro-user-manual-1p5o2cp/
- The existing display module exposes GND, VCC, SCL, SDA, RST, DC, CS, BL, and SDO-compatible pins and has no touch interface.
- There are no existing brand assets, product claims, benchmarks, or implementation files. Future work must not fabricate them.

## Product Principles

- Live behavior is deterministic; editing, display work, and USB transfers never obstruct switch-to-MIDI execution.
- Keep the performance surface small and predictable; configuration complexity stays off-stage.
- Prefer inspectable protocols, documented formats, replaceable modules, and common components.
- Defaults must be safe: relay contacts fail open, configuration updates are atomic, and reboot state is predictable.
- Add a feature only when it improves the core four-switch controller experience.

## Accessibility & Inclusion

The editor must be keyboard-operable, provide visible focus, use clear language, and never rely on color alone to communicate state. Layout must remain usable at browser zoom and on typical laptop displays.
Both editor themes must maintain WCAG AA text, control, state, and focus contrast.

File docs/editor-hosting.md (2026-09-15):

# Hosting the browser editor

The editor is a static site. It does not need an API server, database, login,
rewrite rule, service worker, or analytics endpoint. Build it with:

```bash
pnpm install --frozen-lockfile
pnpm --filter @midi-pedal/editor typecheck
pnpm --filter @midi-pedal/editor test
pnpm --filter @midi-pedal/editor build
```

Publish the contents of `editor/dist/` exactly as generated. Vite uses a
relative asset base, so the site can be mounted at `/`, `/midi-pedal/`, or
another static subpath without changing JavaScript URLs.

The production editor is hosted at
[balazsbencs.github.io/midi-pedal](https://balazsbencs.github.io/midi-pedal/).
Pushes to `main` that change the editor, shared protocol package, workspace
configuration, or editor workflow are tested, built, and deployed by
`.github/workflows/editor.yml`. The workflow can also be run manually from the
GitHub Actions page.

## Secure context and browser support

WebSerial is supported here in desktop Chromium-based browsers: current
Chrome, Edge, and Brave. The deployed origin must be HTTPS; `http://localhost`
is the development exception. The browser asks for the serial port only after
the user presses **Connect pedal**. A denied prompt can be retried from the
same button; no permission is requested during page load.

Safari, Firefox, mobile browsers, and insecure remote HTTP origins are outside
the v1 support boundary. The editor remains useful for JSON editing and
export when no serial API is present, but it cannot sync to a pedal.

## Cache headers

Serve `index.html` with `Cache-Control: no-cache` so a new deployment is
discoverable. Hashed files under `assets/` can use
`Cache-Control: public, max-age=31536000, immutable`. Set JavaScript and CSS
MIME types normally; no fallback rewrite is needed for this single-page app.

## Examples

Cloudflare Pages and GitHub Pages can use `editor/dist` as the output directory
with `pnpm --filter @midi-pedal/editor build` as the build command. For nginx:

```nginx
location /midi-pedal/ {
    alias /srv/midi-pedal/editor/dist/;
    add_header Cache-Control "no-cache" always;
}
location /midi-pedal/assets/ {
    alias /srv/midi-pedal/editor/dist/assets/;
    add_header Cache-Control "public, max-age=31536000, immutable" always;
}
```

Use the same HTTPS hostname for the page and the browser session. The pedal
itself is connected directly over USB; LAN access to the static site does not
create a network path to the device.

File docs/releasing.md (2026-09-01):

# Releasing

Releases use SemVer. The first compatibility tuple is firmware/editor `0.1.x`,
configuration schema 1, binary image format 1, and USB protocol 1. A change to
field meaning, byte order, command lifecycle, or relay/power safety requires a
version bump and compatibility note before it can ship.

## Automatic GitHub releases

Every push to `main` runs `.github/workflows/release.yml`. The workflow uses
the conventional commit subject to calculate the next version from the latest
reachable `vX.Y.Z` tag:

```text
BREAKING CHANGE or feat!: major
feat: minor
fix, perf, refactor, docs, test, build, ci, chore: patch
```

The first release uses the version in the root `package.json`. Subsequent
releases are tagged automatically, so no manual tag or release-draft step is
needed. A rerun of a completed workflow is idempotent when the commit already
has a release tag.

Each release contains the BOOTSEL image `firmware.uf2`, debugger/programmer
images, the generated `CHANGELOG.md`, `SHA256SUMS`, the compatibility
`manifest.json`, and `flashing.md`. The `firmware.uf2` file is the normal
drag-and-drop image for the Pico 2; see [Flashing and recovery](flashing.md).

The simulated HIL report is included in the package and remains `FAIL` while
the repository's physical qualification evidence is incomplete. This keeps
the artifact traceable without presenting an unqualified hardware revision as
stage-ready.

## Local rehearsal

Build from a clean clone, set a stable UTC epoch, and package twice:

```bash
export SOURCE_DATE_EPOCH="$(git show -s --format=%ct HEAD)"
pnpm install --frozen-lockfile
pnpm check
cmake --preset pico2-release
cmake --build --preset pico2-release
pnpm --filter @midi-pedal/editor build
pnpm hil:release -- --rig simulated --report build/hil-simulated.json || true
pnpm release:package -- --version 0.1.0 --out build/release-a
pnpm release:package -- --version 0.1.0 --out build/release-b
cmp build/release-a/SHA256SUMS build/release-b/SHA256SUMS
```

The local packager includes the checked-in `CHANGELOG.md` by default. To
rehearse the exact generated release notes, first write notes with
`node tools/release/next.mjs --notes build/release-notes.md`, then pass
`--changelog build/release-notes.md` to `pnpm release:package`.

The simulated HIL report is expected to be `FAIL` while hardware evidence is
missing. It is useful for checking report shape, not for publication.

## Publication gate

Before tagging `v0.1.0`, require a reviewed schematic/PCB revision, generated
Gerbers/drills, signed first-article results, and a real HIL report with no
release-blocking skips. Inspect `manifest.json`, `SHA256SUMS`, firmware map
size, editor archive contents, licenses, and the compatibility tuple. Publish
only after a human reviews the artifact list and release notes.

## Rollback and corrections

Firmware can be rolled back through BOOTSEL while preserving the active
configuration image if the protocol/image tuple remains compatible. Keep a JSON
export before any reset. If a fabrication or safety defect is found, withdraw
the affected artifact, increment the hardware revision, regenerate all outputs,
and document the correction rather than silently replacing files.

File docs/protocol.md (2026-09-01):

# Device protocol

Protocol version 1 is a little-endian, framed request/response protocol carried on the Pico 2 CDC configuration interface at 115200 8N1. The same commands are available while the class-compliant USB-MIDI interface is active; MIDI traffic is independent of configuration frames.

## Frame layout

Every frame is:

| Offset | Size | Field |
| ---: | ---: | --- |
| 0 | 4 | ASCII magic `MPCF` |
| 4 | 2 | protocol version (`u16`, `1`) |
| 6 | 4 | request id (`u32`) |
| 10 | 2 | command (`u16`) |
| 12 | 2 | flags (`u16`, currently zero) |
| 14 | 4 | payload length (`u32`, maximum 4096) |
| 18 | n | payload |
| 18+n | 4 | CRC-32/IEEE over bytes 0 through 17+n |

The decoder accepts arbitrary serial chunk boundaries, ignores noise before the next magic value, and continues after a CRC error. A request id is generated by the editor and is reused for every retry. Firmware caches the latest response for each request id, making retries idempotent.

The host waits 1000 ms for a response and makes three total attempts. A response uses the same frame shape; its payload begins with a status code and command-specific result. The error codes are `CRC_MISMATCH`, `UNSUPPORTED_VERSION`, `PAYLOAD_TOO_LARGE`, `UNKNOWN_COMMAND`, `INVALID_FRAME`, `INCOMPATIBLE_DEVICE`, `INVALID_CONFIGURATION`, `INVALID_STATE`, `VERIFY_FAILED`, and `BUSY`.

## Commands

| Value | Command | Payload |
| ---: | --- | --- |
| 1 | `GET_CAPABILITIES` | empty |
| 2 | `GET_CONFIG_INFO` | empty |
| 3 | `READ_CONFIG` | bank index `u8` (0–127) |
| 4 | `BEGIN_UPLOAD` | image size `u32`, image sequence `u32`, image CRC-32 `u32` |
| 5 | `WRITE_CHUNK` | offset `u32` followed by up to 1024 image bytes |
| 6 | `VERIFY_UPLOAD` | empty |
| 7 | `ACTIVATE_UPLOAD` | empty |
| 8 | `GET_EXPRESSION_SAMPLE` | empty |
| 9 | `SET_EXPRESSION_CALIBRATION` | heel ADC `u16`, toe ADC `u16` |
| 10 | `FACTORY_EMPTY_RESET` | empty |

`GET_CAPABILITIES` reports the device model, firmware version, protocol version, config schema, image format, queue capacity, supported destinations, and expression/relay/display capabilities. `GET_CONFIG_INFO` reports the active image sequence, length, CRC, active slot, and `bankCount`. `READ_CONFIG` returns the exact binary bank record for the requested index, including its leading little-endian record length; it does not return JSON. A host reconstructs the complete document by requesting indexes `0..bankCount-1` and decoding each record with the shared image codec.

The current firmware USB identity is vendor ID `0x2E8A`, product ID `0x4001`, with one CDC ACM configuration interface and one class-compliant USB-MIDI streaming interface. USB serial text uses the Pico's unique board identifier, so a host can distinguish multiple pedals on the same machine.

## Synchronization lifecycle

1. Query capabilities and config metadata.
2. Validate the complete local JSON document and compile one binary image.
3. Send `BEGIN_UPLOAD` with image size, sequence, and CRC.
4. Send contiguous `WRITE_CHUNK` requests, each no larger than 1024 bytes.
5. Send `VERIFY_UPLOAD`; firmware validates the inactive slot and reads it back.
6. Send `ACTIVATE_UPLOAD`; firmware advances the active marker only after verification.
7. Query `GET_CONFIG_INFO` and compare the active sequence, length, and CRC with the compiled image.

Power loss, disconnect, malformed data, a missing chunk, or failed CRC leaves the previous active image selected. The editor reports that previous configuration as intact and may reconnect and retry. `FACTORY_EMPTY_RESET` validates and activates the embedded copy generated from `firmware/defaults/factory-empty.bin`; it never changes firmware.

## Expression calibration

The editor requests a live sample, asks the user to move the pedal to heel and toe, and sends the two measured ADC endpoints. Firmware rejects a span below 410 counts, stores the accepted endpoints in controller-level settings, and reports the result. Invalid or disconnected expression input emits no MIDI.

## Compatibility

A device must reject unsupported protocol versions, config schemas, image formats, and device models before reading or mutating configuration. Adding optional response fields is compatible; changing byte order, field meaning, command lifecycle, or safety behavior requires a protocol or image-format version bump and a compatibility entry in the release manifest.

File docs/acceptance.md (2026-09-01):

# Product acceptance evidence

This table is the release map from the design specification to evidence. A
`PENDING` or `BLOCKED` row with no linked capture keeps a release from being
called qualified.

| Requirement | HIL/manual case | Instrument or automation | Limit/status | Evidence |
|---|---|---|---|---|
| Press-to-MIDI latency | switch.latency-under-50ms | logic analyzer + HIL timestamp | <50 ms | Pending hardware |
| Four approved chords/repeat | switch.chord-* | switch fixture + firmware trace | exact map/timing | Native tests; hardware pending |
| TRS/USB bytes and routing | midi.trs-bytes, midi.usb-packets, midi.per-message-routing | MIDI monitor/logic analyzer | exact bytes/order | Native encoder tests; hardware pending |
| Queue order/overflow | midi.queue-order | deterministic queue test | drop newest only | Native tests |
| Relay open boot/reset/watchdog/brownout/unpowered | relay.* | DMM/continuity logger | contacts open | Pending hardware |
| Expression filtering/calibration | expression.calibration-sweep | 10/25 kΩ sweep + ADC capture | no MIDI when invalid/disconnected | Native tests; hardware pending |
| Display feedback | display.response-under-100ms | panel capture/photograph | visible <100 ms | Renderer goldens; hardware pending |
| USB-only/9 V-only/handover | power.* | current-limited supply + DMM | no reset/backfeed | Pending hardware |
| Interrupted upload recovery | config.interrupted-upload | power-cut fixture + CRC readback | old image remains active | Native ConfigStore tests; hardware pending |
| Editor keyboard/themes/200% | editor.* | Chromium + Playwright | WCAG AA/no required horizontal scroll | Chromium tests |

The current `pnpm hil:release -- --rig simulated` report intentionally records
hardware-dependent rows as release-blocking skips. Attach a real report to a
tagged release only after the first-article and bench records are complete.

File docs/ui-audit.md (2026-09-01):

# Editor UI audit

The editor follows the approved three-pane hierarchy and adds the explicitly
requested Light/Dark switch. This audit records the checks that can be run in
the repository and separates them from hardware/browser evidence that needs a
real device.

## Reviewed decisions

- The physical A/B/C/D order is preserved in a 2×2 map and in DOM reading order.
- Banks, pages, presets, position toggles, message controls, and theme changes
  are real keyboard-operable buttons/inputs with visible focus.
- Status is communicated with text as well as color; validation failures name
  the path and keep Sync disabled.
- At narrower widths the inspector moves below the bank/map columns; at 200%
  zoom the layout can flow vertically without a required horizontal scroll.
- Light and dark palettes use semantic tokens, with `prefers-color-scheme`
  used only for the first visit and explicit choices stored locally.

## Automated evidence

Run:

```bash
pnpm --filter @midi-pedal/editor typecheck
pnpm --filter @midi-pedal/editor test
pnpm --filter @midi-pedal/editor test:e2e
```

The component tests cover theme precedence, keyboard selection, stable
workspace order, dirty draft editing, and simulated transport failures. The
Chromium tests cover labelled controls, theme keyboard reachability, desktop
viewports, narrow layout, and a 200% zoom overflow check.

## Remaining manual evidence

The audit does not claim physical-device success. A release still needs a
current stable Chrome/Edge/Brave pass against a flashed controller, plus
contrast confirmation in the exact hosted font/rendering environment. Record
browser, OS, firmware, and commit in the real-device checklist.

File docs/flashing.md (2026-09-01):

# Flashing and recovery

The Pico 2 firmware is a normal UF2 image. Always disconnect the 9 V supply
before changing USB or SWD wiring, and observe the 9 V center-negative warning
in [hardware-assembly.md](hardware-assembly.md).

## Build the image

```bash
cmake --preset pico2-release
cmake --build --preset pico2-release
```

The image to flash is:

```text
build/pico2-release/firmware/midi_pedal.uf2
```

## BOOTSEL / UF2 (recommended)

1. Unplug the pedal from USB and 9 V.
2. Hold the Pico 2 **BOOTSEL** button while connecting USB.
3. Release BOOTSEL after the removable `RP2350`/`RPI-RP2` volume appears.
4. Copy `midi_pedal.uf2` to that volume.
5. Wait for the volume to disappear and the controller to reboot.

On Linux the volume normally mounts under `/media/$USER/`; macOS shows it in
Finder; Windows assigns it a removable drive letter. Copy the file to the
volume root, not to a subdirectory. Do not unplug while the copy is in
progress. If the volume does not appear, retry with a known data-capable USB
cable and hold BOOTSEL before inserting the cable.

## picotool

With a supported `picotool` on `PATH` and the device in normal USB mode:

```bash
picotool info
picotool load -f build/pico2-release/firmware/midi_pedal.uf2
picotool reboot
```

The `-f` option is an explicit overwrite. Confirm the board identity in the
`info` output before loading an image.

## SWD debug probe

Use a 3.3 V probe only. Connect probe GND, SWDIO, SWCLK, and (if supported)
the target reset line to the Pico 2 debug pads; never apply probe voltage and
9 V pedal power at the same time unless the carrier power design explicitly
isolates them. A typical OpenOCD session is:

```bash
openocd -f interface/cmsis-dap.cfg -f target/rp2350.cfg
```

In a second terminal, load the ELF with the matching GDB:

```bash
arm-none-eabi-gdb build/pico2-release/firmware/midi_pedal.elf
(gdb) target extended-remote :3333
(gdb) monitor reset init
(gdb) load
(gdb) monitor reset run
(gdb) detach
(gdb) quit
```

Probe configuration names vary; use the config supplied by the probe vendor
if `target/rp2350.cfg` is named differently.

## Verify after flashing

Before connecting the editor:

- both isolated relay contacts measure open with a continuity meter;
- the ST7796S shows the 2×2 live screen and expression-unavailable state when
  no pedal is connected;
- the host sees one CDC configuration port and one class-compliant MIDI port;
- a MIDI monitor receives the expected three-byte CC/PC packet from a switch.

The relays are designed normally open in hardware and are driven inactive
before configuration is read. A firmware image cannot substitute for the
continuity checks in [firmware-bench.md](../hardware/validation/firmware-bench.md).

## Factory-empty recovery

If configuration synchronization is interrupted, the previous validated image
remains active. Reconnect the editor and retry the sync. To intentionally
clear the user configuration, use the editor's **Factory empty reset** command
or send `FACTORY_EMPTY_RESET` over CDC; this activates the checked-in image at
`firmware/defaults/factory-empty.bin` and does not change firmware.

If the device does not enumerate, reflash the UF2 first, then reconnect USB
and repeat the reset. Keep a JSON export of the desired configuration before
using a factory reset.

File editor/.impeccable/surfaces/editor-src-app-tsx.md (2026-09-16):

---
version: 1
slug: "editor-src-app-tsx"
primary_target: "editor/src/App.tsx"
related_targets: ["editor/src/ui/workspace.css","editor/src/ui/theme/tokens.css","editor/src/ui/layout/AppHeader.tsx","editor/src/ui/banks/BankList.tsx","editor/src/ui/presets/PageMap.tsx","editor/src/ui/inspector/PresetInspector.tsx","editor/src/ui/layout/StatusBar.tsx"]
---

# Browser editor surface brief

- Mode: operate. A musician or builder must move from bank selection to preset editing and device synchronization without losing page or switch context.
- Direction: Studio Console, built literally from the approved concept. The full-width command bar, bank rail, oversized colored A–D deck, tall inspector, compact status floor, dark material, and dense sans-serif hierarchy are the surface—not loose inspiration.
- Memorable moment: four luminous, near-square cyan/coral/violet/yellow switch fields make the physical A–D pedal map unmistakable before any control is read; the selected color continues into the inspector.
- Primary task: choose a bank and page, select a switch, edit its presentation and ordered messages, validate, then sync or export.
- Constraints: preserve all current behavior and copy, 128 searchable banks, fixed A–D order, explicit light/dark themes, keyboard access, laptop and 200% zoom support, no backend, and no decorative charts or invented device capabilities.
- Responsive rule: keep rail, map, and inspector together on wide screens; place the inspector below the map on compact laptops; stack all regions on phones while keeping every device and file action reachable.

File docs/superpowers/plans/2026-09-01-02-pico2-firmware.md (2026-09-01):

# Pico 2 Firmware Implementation Plan

> **For agentic workers:** REQUIRED SUB-SKILL: Use superpowers:subagent-driven-development (recommended) or superpowers:executing-plans to implement this plan task-by-task. Steps use checkbox (`- [ ]`) syntax for tracking.

**Goal:** Build and verify deterministic Pico 2 firmware for four switches, expression, TRS/USB MIDI, two fail-open relays, atomic configuration storage, and the ST7796S display.

**Architecture:** Hardware-independent C++ core modules consume timestamped inputs and produce bounded commands through abstract ports. Pico-specific HAL code owns GPIO, ADC, UART, SPI/DMA, flash, watchdog, and TinyUSB; the main loop polls non-blocking services on one core without an RTOS.

**Tech Stack:** C++20, Raspberry Pi Pico SDK 2.2.0, TinyUSB from that SDK, CMake/Ninja, GoogleTest/CTest, Arm GNU Toolchain, picotool, OpenOCD.

**Spec:** `docs/superpowers/specs/2026-09-01-midi-controller-pedal-design.md`

## Global Constraints

- Pin map: switches GP2–GP5; UART1 TX GP8; relays GP10–GP11; display CS GP17, SPI0 SCK GP18, SPI0 MOSI GP19, DC GP20, RST GP21; expression ADC0 GP26.
- Display backlight is hardwired on and SDO is not connected.
- Fixed timing: debounce 20 ms, chord 35 ms from first edge, double tap 300 ms, long press 500 ms, repeat delay 600 ms, repeat interval 200 ms.
- TRS and USB each use a 64-message queue; normal press-to-MIDI is under 50 ms and display response begins under 100 ms.
- Relays initialize open in hardware and software before configuration is read.
- Flash layout on 4 MiB Pico 2: firmware below `0x200000`; slot A `0x200000..0x2EFFFF`; slot B `0x2F0000..0x3DFFFF`; metadata `0x3E0000..0x3FFFFF`; maximum image 768 KiB.

### Current WIP status (2026-09-01)

The host-tested core, A/B configuration store, composite CDC + USB-MIDI
protocol path, Pico flash/USB adapters, embedded factory image, and the
switch/action/expression runtime integration are present on `main`.
Watchdog/reset handling, fixed-rate expression scheduling, persistent
expression calibration, and upload busy hardening are now implemented.
Physical relay, MIDI, expression, display, power, and USB enumeration
qualification is still required before a stage-use release.

---

### Task 1: Firmware build, board contract, and safe boot shell

**Files:**
- Add submodule: `third_party/pico-sdk` at tag `2.2.0`
- Create: `firmware/pico_sdk_import.cmake`
- Create: `firmware/src/board/pico2_pins.hpp`
- Create: `firmware/src/hal/ports.hpp`
- Create: `firmware/src/app/controller.hpp`
- Create: `firmware/src/app/controller.cpp`
- Create: `firmware/src/main.cpp`
- Create: `firmware/tests/controller_boot_test.cpp`
- Modify: `firmware/CMakeLists.txt`
- Modify: `CMakePresets.json`

**Interfaces:**
- Consumes: `ImageReader` from Plan 1.
- Produces: `Controller::initialize()` and abstract `Clock`, `MidiPort`, `RelayPort`, `DisplayPort`, `ConfigStore`, and `DiagnosticPort` interfaces.

- [ ] **Step 1: Write the failing safe-boot test**

```cpp
TEST(ControllerBoot, OpensRelaysBeforeReadingConfiguration) {
  FakeHal hal;
  midi::Controller controller(hal);
  controller.initialize();
  EXPECT_EQ(hal.calls[0], "relay1:open");
  EXPECT_EQ(hal.calls[1], "relay2:open");
  EXPECT_LT(hal.index_of("relay2:open"), hal.index_of("config:read"));
}
```

- [ ] **Step 2: Run and observe failure**

Run: `cmake --preset host-debug && cmake --build --preset host-debug && ctest --preset host-debug -R ControllerBoot`

Expected: compile failure because controller and ports do not exist.

- [ ] **Step 3: Define ports and board pins**

```cpp
struct MidiMessage { std::array<uint8_t, 3> bytes{}; uint8_t length{}; };
enum class Destination : uint8_t { Trs, Usb, Both };
struct RelayPort { virtual void set(uint8_t contact, bool closed) = 0; };
struct MidiPort { virtual bool enqueue(Destination, MidiMessage) = 0; };
struct DisplayPort { virtual void present(const LiveView&) = 0; };
```

Add compile-time assertions that all assigned GPIOs are unique and GP26 is ADC capable.

- [ ] **Step 4: Implement minimal safe initialization and empty-config fallback**

`main()` initializes relay GPIOs to inactive before creating other services, then initializes watchdog, config store, controller, USB, UART, ADC, and display. If neither slot is valid, load an in-memory empty configuration and expose CDC immediately.

- [ ] **Step 5: Build host and Pico targets**

Run: `cmake --preset host-debug && cmake --build --preset host-debug && ctest --preset host-debug && cmake --preset pico2-release && cmake --build --preset pico2-release`

Expected: tests pass and `build/pico2-release/firmware/midi_pedal.uf2` exists.

- [ ] **Step 6: Commit**

```bash
git add .gitmodules third_party/pico-sdk firmware CMakePresets.json
git commit -m "build(firmware): boot Pico 2 into a safe controller shell"
```

### Task 2: Deterministic footswitch and chord engine

**Files:**
- Create: `firmware/src/core/switch_engine.hpp`
- Create: `firmware/src/core/switch_engine.cpp`
- Create: `firmware/tests/switch_engine_test.cpp`

**Interfaces:**
- Consumes: raw switch bitmask and monotonic milliseconds.
- Produces: `SwitchEvent { EventKind kind; SwitchId switch_id; Chord chord; uint32_t at_ms; }` through `SwitchEngine::update(uint8_t raw_mask, uint32_t now_ms)`.

- [ ] **Step 1: Write a table-driven failing timing test**

```cpp
TEST(SwitchEngine, SuppressesAAndCWhenBankDownChordStabilizes) {
  SwitchEngine engine;
  engine.update(mask(A), 0);
  engine.update(mask(A) | mask(C), 12);
  auto events = engine.update(mask(A) | mask(C), 35);
  EXPECT_THAT(events, ElementsAre(ChordEvent(Chord::BankDown)));
}

TEST(SwitchEngine, EmitsSinglePressAtChordDeadline) {
  SwitchEngine engine;
  engine.update(mask(B), 0);
  EXPECT_TRUE(engine.update(mask(B), 34).empty());
  EXPECT_THAT(engine.update(mask(B), 35), ElementsAre(PressEvent(B)));
}
```

- [ ] **Step 2: Run and observe failure**

Run: `ctest --preset host-debug -R SwitchEngine --output-on-failure`

Expected: test executable is absent or fails to compile.

- [ ] **Step 3: Implement debounce and chord recognition as explicit states**

Use `Idle`, `ChordCandidate`, `SingleActive`, and `ChordActive`. Start the 35 ms chord deadline at the first physical edge; accept only switch levels stable for 20 ms; map only the four approved chords; suppress press/release/long/double events while `ChordActive`.

- [ ] **Step 4: Add gesture and wraparound tests**

Test release, press-plus-long, press/press-plus-double, 600/200 ms hold repeat, bank 1↔128 wrap, page 1↔4 wrap, near-simultaneous invalid combinations, contact bounce, and 32-bit millisecond wraparound.

- [ ] **Step 5: Run all switch tests and measure runtime**

Run: `ctest --preset host-debug -R SwitchEngine --output-on-failure`

Expected: all cases pass; a 100,000-update benchmark completes without allocation.

- [ ] **Step 6: Commit**

```bash
git add firmware/src/core/switch_engine.* firmware/tests/switch_engine_test.cpp
git commit -m "feat(firmware): recognize switch gestures and navigation chords"
```

### Task 3: Action engine, toggle state, and output queues

**Files:**
- Create: `firmware/src/core/action_engine.hpp`
- Create: `firmware/src/core/action_engine.cpp`
- Create: `firmware/src/core/midi_queue.hpp`
- Create: `firmware/tests/action_engine_test.cpp`
- Create: `firmware/tests/midi_queue_test.cpp`
- Modify: `firmware/src/app/controller.cpp`

**Interfaces:**
- Consumes: `SwitchEvent`, current `BankConfig`, and the compact 2048-preset toggle bitset.
- Produces: ordered `MidiMessage`, `RelayCommand`, `NavigationCommand`, dirty `LiveView`, and diagnostics.

- [ ] **Step 1: Write failing ordering and state tests**

```cpp
TEST(ActionEngine, QueuesMatchingSlotsBeforeToggling) {
  auto preset = preset_with_cc_then_relay_and_toggle_on(Trigger::Press);
  EngineState state{};
  auto result = run_press(preset, state);
  EXPECT_THAT(result.commands, ElementsAre(Cc(1, 17, 127, Destination::Both), RelayClose(1)));
  EXPECT_EQ(state.position(preset_id), Position::Two);
}
```

- [ ] **Step 2: Run and observe failure**

Run: `ctest --preset host-debug -R 'ActionEngine|MidiQueue' --output-on-failure`

Expected: compile failure because engines are absent.

- [ ] **Step 3: Implement exact filtering and MIDI encoding**

Filter slots by trigger and pre-transition position; encode PC as `0xC0 | channel-1, program` and CC as `0xB0 | channel-1, controller, value`; append commands in slot order; transition only after every command is accepted or diagnosed.

- [ ] **Step 4: Implement separate fixed 64-entry TRS and USB queues**

`Destination::Both` attempts both queues independently. If one queue is full or USB unavailable, preserve the other output and increment `Diagnostic::TrsQueueOverflow`, `UsbQueueOverflow`, or `UsbUnavailable`; never overwrite an older entry.

- [ ] **Step 5: Test full capacity and every message variant**

Run: `ctest --preset host-debug -R 'ActionEngine|MidiQueue' --output-on-failure`

Expected: exact bytes/order, navigation, relay, session state retention, boot reset, and overflow policies pass.

- [ ] **Step 6: Commit**

```bash
git add firmware/src/core firmware/tests firmware/src/app/controller.cpp
git commit -m "feat(firmware): execute ordered preset actions"
```

### Task 4: Expression calibration and filtering

**Files:**
- Create: `firmware/src/core/expression.hpp`
- Create: `firmware/src/core/expression.cpp`
- Create: `firmware/tests/expression_test.cpp`
- Modify: `firmware/src/app/controller.cpp`

**Interfaces:**
- Consumes: 12-bit ADC samples at 1 kHz, global heel/toe calibration, and current bank assignment.
- Produces: optional CC command and `ExpressionView { available, value }`.

- [ ] **Step 1: Write failing filter/rate tests**

```cpp
TEST(Expression, FiltersSpikeAndRateLimitsChanges) {
  ExpressionProcessor p(Calibration{400, 3600});
  feed(p, {400, 402, 4095, 401, 403}, 0);
  EXPECT_EQ(p.view().value, 0);
  EXPECT_FALSE(p.sample(2000, 10).has_value());
  EXPECT_TRUE(p.sample(2000, 20).has_value());
}
```

- [ ] **Step 2: Run and observe failure**

Run: `ctest --preset host-debug -R Expression --output-on-failure`

Expected: compile failure because processor is absent.

- [ ] **Step 3: Implement specified signal path**

Maintain a rolling five-sample median, IIR `filtered += 0.2f * (median-filtered)`, calibrated clamp/map, inversion, output range, one-value hysteresis, and a 20 ms minimum MIDI interval. Treat calibration spans below 410 ADC counts as invalid.

- [ ] **Step 4: Add endpoint/noise/disconnect tests**

Cover exact heel/toe, reversed calibration rejection, inversion, minimum/maximum swap, jitter around a MIDI boundary, unplug/open-circuit samples, bank change, disabled assignment, and TRS/USB/both destinations.

- [ ] **Step 5: Run expression and action tests**

Run: `ctest --preset host-debug -R 'Expression|ActionEngine' --output-on-failure`

Expected: all tests pass and no unchanged CC is emitted.

- [ ] **Step 6: Commit**

```bash
git add firmware/src/core/expression.* firmware/tests/expression_test.cpp firmware/src/app/controller.cpp
git commit -m "feat(firmware): process calibrated expression input"
```

### Task 5: Atomic A/B flash configuration store

**Files:**
- Create: `firmware/src/core/config_store.hpp`
- Create: `firmware/src/core/config_store.cpp`
- Create: `firmware/src/hal/pico_flash_port.hpp`
- Create: `firmware/src/hal/pico_flash_port.cpp`
- Create: `firmware/tests/config_store_test.cpp`
- Modify: `firmware/src/app/controller.cpp`

**Interfaces:**
- Produces: `begin_upload(size, sequence)`, `write_chunk(offset, bytes)`, `verify_upload()`, `activate_upload()`, `active_info()`, and `load_bank(index)`.
- Consumes: `FlashPort` with erase/program/read and Plan 1 `ImageReader`.

- [ ] **Step 1: Write failing power-cut sequence tests**

Create a `FakeFlash` that can stop after each erase/program operation. For every cut point, reconstruct `ConfigStore` and assert it selects the previous slot until new image readback and metadata activation both finish.

- [ ] **Step 2: Run and observe failure**

Run: `ctest --preset host-debug -R ConfigStore --output-on-failure`

Expected: compile failure because store is absent.

- [ ] **Step 3: Implement slot and metadata records**

Use two redundant metadata sectors with magic, metadata version, generation, active slot, active image sequence/length/CRC, and metadata CRC. Write image chunks only to the inactive slot. Verify using flash readback and `ImageReader`; activate by writing the next metadata generation to the older metadata sector.

- [ ] **Step 4: Implement Pico flash operations safely**

Use SDK flash-safe execution, 4096-byte erase alignment, 256-byte program alignment, and interrupts disabled only inside bounded erase/program calls. Refuse uploads during a live action and expose busy status over CDC.

- [ ] **Step 5: Run exhaustive interruption tests**

Run: `ctest --preset host-debug -R ConfigStore --output-on-failure`

Expected: valid newest slot, corrupt newest fallback, both invalid empty fallback, duplicate activation idempotency, misaligned write rejection, and every simulated cut point pass.

- [ ] **Step 6: Commit**

```bash
git add firmware/src/core/config_store.* firmware/src/hal/pico_flash_store.* firmware/tests/config_store_test.cpp firmware/src/app/controller.cpp
git commit -m "feat(firmware): activate configurations atomically"
```

### Task 6: Composite CDC and USB-MIDI device

**Files:**
- Create: `firmware/src/usb/usb_descriptors.c`
- Create: `firmware/src/usb/usb_transport.hpp`
- Create: `firmware/src/usb/usb_transport.cpp`
- Create: `firmware/src/core/frame_decoder.hpp`
- Create: `firmware/src/core/frame_decoder.cpp`
- Create: `firmware/tests/frame_decoder_test.cpp`
- Create: `firmware/tests/usb_descriptor_test.cpp`
- Modify: `firmware/CMakeLists.txt`

**Interfaces:**
- Consumes: frame contract from Plan 1, `ConfigStore`, expression calibration, and USB MIDI queue.
- Produces: TinyUSB composite device with one MIDI streaming interface and one CDC ACM interface.

- [ ] **Step 1: Write failing descriptor and frame-fixture tests**

Assert one configuration exposes CDC control/data plus Audio/MIDI interfaces, endpoint numbers fit RP2350 limits, strings include product and serial, and C++ frame decoding matches every `protocol/fixtures/frames` vector.

- [ ] **Step 2: Run and observe failure**

Run: `ctest --preset host-debug -R 'UsbDescriptor|FrameDecoder' --output-on-failure`

Expected: compile failure because descriptors and decoder are absent.

- [ ] **Step 3: Implement TinyUSB descriptors and non-blocking tasks**

Assign CDC bulk endpoints and one MIDI IN endpoint, service `tud_task()` every main-loop iteration, drain USB MIDI only when mounted/ready, and parse CDC bytes incrementally without waiting. Use Pico unique board id for USB serial text.

- [ ] **Step 4: Dispatch all protocol commands idempotently**

Connect capability, metadata, read, staged upload, verify, activate, calibration, and factory-empty commands to controller services. Cache the final encoded response for the most recent 16 request ids.

- [ ] **Step 5: Verify on host and Pico 2**

Run host tests, flash the UF2, then verify `GET_CAPABILITIES`, MIDI enumeration, and a three-byte note-free CC packet using `lsusb`/Device Manager/System Information and a MIDI monitor. Record USB VID/PID selection procedure in `docs/protocol.md` before public release.

- [ ] **Step 6: Commit**

```bash
git add firmware/src/usb firmware/src/core/frame_decoder.* firmware/tests firmware/CMakeLists.txt docs/protocol.md
git commit -m "feat(firmware): expose composite USB MIDI and configuration"
```

### Task 7: Pico GPIO/UART/ADC/relay HAL and fail-open behavior

**Files:**
- Create: `firmware/src/hal/pico_switches.hpp`
- Create: `firmware/src/hal/pico_switches.cpp`
- Create: `firmware/src/hal/pico_uart_midi.hpp`
- Create: `firmware/src/hal/pico_uart_midi.cpp`
- Create: `firmware/src/hal/pico_expression_adc.hpp`
- Create: `firmware/src/hal/pico_expression_adc.cpp`
- Create: `firmware/src/hal/pico_relays.hpp`
- Create: `firmware/src/hal/pico_relays.cpp`
- Create: `firmware/src/app/pedal_runtime.hpp`
- Create: `firmware/src/app/pedal_runtime.cpp`
- Create: `firmware/tests/pico_hal_contract_test.cpp`
- Create: `firmware/tests/pedal_runtime_test.cpp`
- Modify: `firmware/src/main.cpp`

**Interfaces:**
- Implements the ports from Task 1 and feeds the core at fixed cadence.

- [ ] **Step 1: Add failing HAL contract tests**

Compile Pico HAL against fake SDK shims and assert relay GPIO direction/value order, UART 31,250 baud 8N1, ADC0/GP26 selection, switch pull states, and MIDI queue draining without blocking.

- [ ] **Step 2: Run and observe failure**

Run: `ctest --preset host-debug -R PicoHalContract --output-on-failure`

Expected: compile failure because HAL modules are absent.

- [ ] **Step 3: Implement hardware services**

Initialize relays inactive before setting output direction; use UART1 at 31,250 baud; sample ADC from a repeating timer/FIFO at 1 kHz; read switch GPIO as one bitmask; drain at most one MIDI message per ready UART opportunity to keep the loop non-blocking.

- [ ] **Step 4: Bench-test electrical behavior**

Use a logic analyzer to confirm MIDI baud/bytes and press latency; use continuity mode to verify both relay contacts remain open during reset button hold, BOOTSEL boot, watchdog reset, power ramp, and unplug; record results under `hardware/validation/firmware-bench.md`.

- [ ] **Step 5: Run tests and Pico release build**

Run: `pnpm check && cmake --preset pico2-release && cmake --build --preset pico2-release`

Expected: all host tests pass and release UF2/ELF/map files build.

- [ ] **Step 6: Commit**

```bash
git add firmware/src/hal firmware/src/main.cpp firmware/tests hardware/validation/firmware-bench.md
git commit -m "feat(firmware): drive Pico 2 pedal interfaces"
```

### Task 8: ST7796S driver and fixed live renderer

**Files:**
- Create: `firmware/src/display/st7796s.hpp`
- Create: `firmware/src/display/st7796s.cpp`
- Create: `firmware/src/display/live_renderer.hpp`
- Create: `firmware/src/display/live_renderer.cpp`
- Create: `firmware/src/display/font_ascii.hpp`
- Create: `firmware/src/display/font_ascii.cpp`
- Create: `firmware/tests/live_renderer_test.cpp`
- Create: `firmware/tests/golden/display/factory-empty.rgb565`
- Create: `firmware/tests/golden/display/toggle-position-1.rgb565`
- Create: `firmware/tests/golden/display/toggle-position-2.rgb565`
- Create: `firmware/tests/golden/display/expression-unavailable.rgb565`
- Create: `firmware/tests/golden/display/recoverable-error.rgb565`
- Modify: `firmware/src/main.cpp`

**Interfaces:**
- Consumes: `LiveView` containing bank/page, four position views, expression, USB/config diagnostic indicators.
- Produces: clipped dirty rectangles sent over SPI0/DMA; no full framebuffer.

- [ ] **Step 1: Write failing geometry and snapshot tests**

Assert header/footer heights, A/B/C/D quadrant coordinates, 12-character labels, Position 1/2 text markers, unavailable expression state, and unchanged-view zero-transfer behavior against RGB565 golden regions.

- [ ] **Step 2: Run and observe failure**

Run: `ctest --preset host-debug -R LiveRenderer --output-on-failure`

Expected: compile failure because renderer is absent.

- [ ] **Step 3: Implement ST7796S write-only SPI/DMA**

Initialize 480×320 landscape orientation, RGB565 color order, CS/DC/RST control, 32 MHz SPI, address-window writes, and one 4 KiB line/tile buffer. Queue DMA only after the previous transfer completes.

- [ ] **Step 4: Implement the approved 2×2 layout**

Render bank header, B/P numbers, A–D quadrants with fixed white text plus accent/state indicator, and expression footer with label/value/bar or unavailable marker. Add brief non-modal text/icon indicators for USB connection, configuration activation, queue overflow, and recoverable configuration errors. Update only regions whose view model changed.

- [ ] **Step 5: Verify snapshots and physical display**

Run host snapshot tests, flash Pico 2, photograph all required states, and record measured full-screen/dirty update times in `hardware/validation/display.md`. Dirty action feedback must begin within 100 ms.

- [ ] **Step 6: Commit**

```bash
git add firmware/src/display firmware/tests firmware/src/main.cpp hardware/validation/display.md
git commit -m "feat(firmware): render the live pedal display"
```

### Task 9: Verified firmware build and flashing documentation

**Files:**
- Create: `docs/flashing.md`
- Create: `firmware/defaults/factory-empty.json`
- Create: `firmware/defaults/factory-empty.bin`
- Modify: `docs/building.md`
- Modify: `README.md`
- Create: `.github/workflows/firmware.yml`

**Interfaces:**
- Produces: clean-clone UF2 build, BOOTSEL and debug-probe procedures, recovery flow, and CI artifact.

- [ ] **Step 1: Test the documented clean-clone commands in a temporary clone**

```bash
git clone --recurse-submodules . /tmp/midi-pedal-doc-test
cmake --preset pico2-release -S /tmp/midi-pedal-doc-test
cmake --build --preset pico2-release
```

Expected before documentation changes: a reader cannot discover all prerequisites or the UF2 path from README.

- [ ] **Step 2: Write `docs/flashing.md`**

Document:

```text
BOOTSEL/UF2: unplug, hold BOOTSEL, connect USB, release, copy midi_pedal.uf2 to RP2350, wait for reboot.
picotool: picotool load -f build/pico2-release/firmware/midi_pedal.uf2 && picotool reboot.
Debug probe: SWD wiring, OpenOCD command, GDB load/reset command.
Recovery: reflash firmware; reconnect editor; issue factory-empty reset; resync JSON backup.
Verification: USB CDC + MIDI enumerate, empty 2×2 screen appears, both relays measure open.
```

Include Linux, macOS, and Windows device-volume notes and warnings about 9 V polarity and relay/expression/MIDI jack identity.

- [ ] **Step 3: Append exact firmware commands to `docs/building.md` and README**

List tool versions, submodule initialization, Debug/Release preset commands, native tests, output file locations, map-size inspection, and direct links to flashing and troubleshooting.

- [ ] **Step 4: Add firmware CI**

Build native tests and `pico2-release`, upload UF2/ELF/map as CI artifacts, verify factory-empty JSON regenerates the committed binary without diff, and fail when firmware exceeds the 2 MiB boundary.

- [ ] **Step 5: Run the firmware phase gate**

Run: `pnpm check && cmake --preset pico2-release && cmake --build --preset pico2-release && test -f build/pico2-release/firmware/midi_pedal.uf2`

Expected: all tests pass and UF2 exists at the documented path.

- [ ] **Step 6: Commit**

```bash
git add README.md docs/building.md docs/flashing.md firmware/defaults .github/workflows/firmware.yml
git commit -m "docs: add verified firmware build and flashing guide"
```

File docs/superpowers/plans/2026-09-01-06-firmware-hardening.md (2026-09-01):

# Pico 2 firmware hardening follow-up

> This follow-up executes the five reliability items requested after the WIP firmware baseline. Use Superpowers subagent-driven development and test-driven development for each task.

**Goal:** Make the current Pico 2 firmware safer to run unattended by adding watchdog/reset diagnostics, deterministic expression sampling cadence, persistent expression calibration, live-action upload protection, and useful labeled/diagnostic display output.

**Spec authority:** `docs/superpowers/specs/2026-09-01-midi-controller-pedal-design.md` and the existing firmware interfaces in `docs/superpowers/plans/2026-09-01-02-pico2-firmware.md`.

## Global constraints

- Keep the existing four-switch, MIDI-out-only product scope and pin map unchanged.
- Preserve the non-blocking single-loop architecture; do not add an RTOS, wireless stack, MIDI input, touch handling, or new user controls.
- Watchdog timeout is 2000 ms. GPIO relays must be initialized open before configuration is read, including after a watchdog-caused reboot.
- Expression ADC sampling is scheduled at a 1 ms cadence (1 kHz) and the expression processor's existing 20 ms MIDI rate limit remains authoritative.
- Expression calibration remains global/controller-level state, is accepted only when toe > heel and the span is at least 410 ADC counts, and must survive a `ConfigStore` reconstruction.
- Configuration mutations that can erase/program flash return protocol `BUSY` while a live switch/chord action is executing. The existing idempotent frame behavior and error names remain unchanged.
- Display remains 480x320 landscape, write-only ST7796S, dirty-region only, and no full framebuffer. Labels are printable ASCII and must be clipped to their existing 12-character/20-character limits.
- Existing protocol/image versions, flash slot offsets, queue sizes, and USB identities do not change.
- No physical hardware is available during this pass; hardware-specific behavior must remain behind existing HAL boundaries and be covered by host tests where possible.

## Task 1: Watchdog/reset handling and fixed-rate expression scheduling

**Files:**
- Add `firmware/src/hal/pico_watchdog.hpp` and `.cpp`.
- Modify `firmware/src/main.cpp`, `firmware/src/app/pedal_runtime.hpp`, `firmware/src/app/pedal_runtime.cpp`, `firmware/tests/pico_hal_contract_test.cpp`, `firmware/tests/pedal_runtime_test.cpp`, and `firmware/CMakeLists.txt` as needed.

Implement `PicoWatchdog` with `TimeoutMs == 2000`, a safe `initialize()` that samples `watchdog_caused_reboot()` before enabling the watchdog, and an idempotent `feed()` used once per main-loop iteration. Feed the watchdog after USB/runtime/MIDI services. Pass the reset-cause bit into `PedalRuntime` so it can expose a diagnostic flag in its `LiveView`.

Move expression reads behind a runtime scheduler that requests at most one ADC sample per due 1 ms period, catches up safely after a delayed loop without a burst, and preserves millisecond wraparound behavior. Add tests that prove repeated `tick()` calls at the same timestamp do not read the ADC repeatedly and that a later timestamp resumes the 1 kHz schedule.

Use TDD: add failing tests first, observe the expected failure, implement the smallest change, then run focused tests and the full native suite before committing.

## Task 2: Persistent calibration and upload/live-action busy protection

**Files:**
- Modify `firmware/src/core/config_store.hpp`, `firmware/src/core/config_store.cpp`, `firmware/src/app/controller_protocol_service.hpp`, `firmware/src/app/controller_protocol_service.cpp`, `firmware/src/app/pedal_runtime.hpp`, `firmware/src/app/pedal_runtime.cpp`, `firmware/src/main.cpp`, `firmware/tests/config_store_test.cpp`, `firmware/tests/controller_protocol_service_test.cpp`, and `firmware/tests/pedal_runtime_test.cpp`.

Add a redundant settings record inside each existing metadata sector without changing the image slot layout or metadata image record. Store a generation, heel ADC, toe ADC, and CRC; scan the newest valid settings independently of the active image. Preserve settings when activating a new image, support calibration persistence even before the first image exists, and default to `{0,4095}` when no valid record exists. Expose `ConfigStore::expression_calibration()` and `set_expression_calibration()`.

Add a `LiveActionState`/probe interface implemented by `PedalRuntime`. Mark the state around switch/chord action execution. `ControllerProtocolService` must reject `BEGIN_UPLOAD`, `WRITE_CHUNK`, `VERIFY_UPLOAD`, `ACTIVATE_UPLOAD`, `FACTORY_EMPTY_RESET`, and calibration writes with `ServiceError::Busy` while the probe reports active; otherwise retain the existing error mapping. Wire the probe in `main()` after constructing the runtime. Ensure failed persistence does not leave the in-memory processor on an uncommitted calibration.

Use TDD with reconstruction/power-cut-style settings tests, service busy tests, and runtime state tests. Keep settings writes bounded and non-allocating.

## Task 3: Rich labeled display and diagnostics

**Files:**
- Modify `firmware/src/hal/ports.hpp`, `firmware/src/app/pedal_runtime.hpp`, `firmware/src/app/pedal_runtime.cpp`, `firmware/src/display/live_renderer.hpp`, `firmware/src/display/live_renderer.cpp`, `firmware/tests/live_renderer_test.cpp`, `firmware/tests/display_golden_generator.cpp`, and committed display goldens as needed.

Extend `LiveView` with the bank name, each switch's currently selected position label/accent, the expression assignment label, and a watchdog-reset diagnostic bit. Populate those fields from the active `BankConfig` and `ExpressionProcessor`; use bounded empty/fallback labels when no image is active. Include the new fields in dirty-view comparison.

Update the renderer while preserving the approved geometry: show the bank name and bank/page numbers in the header, render the selected A/B/C/D label and position marker with its configured accent, show the expression assignment label and value/bar or unavailable marker in the footer, and make USB/configuration/queue/watchdog diagnostics legible without changing controls or adding touch. Keep all writes clipped and dirty-only. Update the golden generator/tests to assert label pixels, diagnostics, and unchanged-view zero-transfer behavior.

Use TDD and regenerate goldens only after focused renderer tests demonstrate the intended behavior.

## Verification gate

Run:

```text
pnpm check
cmake --preset pico2-release
cmake --build --preset pico2-release -j2
test -f build/pico2-release/firmware/midi_pedal.uf2
```

Record that physical relay/MIDI/display/power qualification still requires the user's Pico and carrier hardware.

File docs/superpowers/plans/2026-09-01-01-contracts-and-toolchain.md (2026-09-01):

# Shared Contracts and Toolchain Implementation Plan

> **For agentic workers:** REQUIRED SUB-SKILL: Use superpowers:subagent-driven-development (recommended) or superpowers:executing-plans to implement this plan task-by-task. Steps use checkbox (`- [ ]`) syntax for tracking.

**Goal:** Establish a reproducible repository and one tested configuration/protocol contract consumed by both firmware and editor.

**Architecture:** A TypeScript package owns the canonical JSON model, JSON Schema, binary encoder/reader, CRC-32, and USB frames. A hardware-independent C++ library decodes the same binary fixtures; CI rejects any cross-language drift before device or UI code depends on it.

**Tech Stack:** Node.js 24 LTS, pnpm 10, TypeScript 5.9, Vitest 4.1, C++20, CMake 3.25+, Ninja, CTest, GoogleTest 1.17, GitHub Actions.

**Spec:** `docs/superpowers/specs/2026-09-01-midi-controller-pedal-design.md`

## Global Constraints

- The portable format is versioned JSON; the device format is little-endian binary with explicit lengths and CRC-32.
- Capacity is exactly 128 banks, four pages, four presets, eight slots, and one expression assignment per bank.
- Reject unknown behavioral fields, invalid ASCII labels, out-of-range MIDI values, invalid relay contacts, and unsupported schema versions.
- Later plans import `@midi-pedal/protocol`; they must not duplicate TypeScript protocol types.
- Firmware parsing performs no dynamic allocation and never reads past caller-provided spans.

---

### Task 1: Reproducible root toolchain and contributor entry point

**Files:**
- Create: `.nvmrc`
- Create: `package.json`
- Create: `pnpm-workspace.yaml`
- Create: `CMakeLists.txt`
- Create: `CMakePresets.json`
- Create: `cmake/GoogleTest.cmake`
- Create: `tools/check-toolchain.mjs`
- Create: `README.md`
- Create: `docs/building.md`
- Modify: `.gitignore`

**Interfaces:**
- Consumes: Node.js 24, Corepack/pnpm 10, CMake, Ninja, and an Arm GNU toolchain visible on `PATH`.
- Produces: `pnpm check`, CMake preset `host-debug`, and documented clean-clone setup commands used by every later plan.

- [ ] **Step 1: Write the failing toolchain smoke check**

```js
// tools/check-toolchain.mjs
import { execFileSync } from "node:child_process";

const checks = [["node", ["--version"]], ["pnpm", ["--version"]], ["cmake", ["--version"]], ["ninja", ["--version"]]];
for (const [bin, args] of checks) execFileSync(bin, args, { stdio: "inherit" });
```

- [ ] **Step 2: Run it before the root scripts exist**

Run: `pnpm check`

Expected: FAIL because `package.json` does not define `check`.

- [ ] **Step 3: Add pinned project metadata and build presets**

```json
{
  "name": "midi-pedal",
  "private": true,
  "packageManager": "pnpm@10.15.0",
  "engines": { "node": ">=24 <25" },
  "scripts": {
    "check:toolchain": "node tools/check-toolchain.mjs",
    "test:ts": "pnpm -r test",
    "test:cpp": "cmake --preset host-debug && cmake --build --preset host-debug && ctest --preset host-debug",
    "check": "pnpm check:toolchain && pnpm test:ts && pnpm test:cpp"
  }
}
```

Set `.nvmrc` to `24`, make the host preset generate `build/host-debug` with Ninja, and fetch GoogleTest `v1.17.0` only for host tests.

- [ ] **Step 4: Write the initial README and build guide**

`README.md` must state the project scope, current implementation status, repository map, required hardware, supported host platforms, license intent, and the shortest commands:

```bash
corepack enable
pnpm install --frozen-lockfile
pnpm check
```

`docs/building.md` must explain Linux, macOS, and Windows installation for Node 24, pnpm 10, CMake, Ninja, Git submodules, Arm GNU Toolchain, and Pico SDK; later firmware/editor tasks append only commands they have run successfully.

- [ ] **Step 5: Verify from repository root**

Run: `corepack enable && pnpm install && pnpm check:toolchain && cmake --preset host-debug`

Expected: all version commands succeed and CMake generates `build/host-debug`.

- [ ] **Step 6: Commit**

```bash
git add .nvmrc package.json pnpm-lock.yaml pnpm-workspace.yaml CMakeLists.txt CMakePresets.json cmake tools README.md docs/building.md .gitignore
git commit -m "build: establish reproducible host toolchain"
```
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

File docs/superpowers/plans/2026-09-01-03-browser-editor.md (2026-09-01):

# Static Browser Editor Implementation Plan

> **For agentic workers:** REQUIRED SUB-SKILL: Use superpowers:subagent-driven-development (recommended) or superpowers:executing-plans to implement this plan task-by-task. Steps use checkbox (`- [ ]`) syntax for tracking.

**Goal:** Deliver an accessible static Chromium editor that manages local drafts, JSON backup, and atomic USB synchronization with the Pico 2 pedal.

**Architecture:** React renders an operate-mode three-pane workspace over a framework-independent domain store. `@midi-pedal/protocol` owns all configuration and frame types; a `DeviceTransport` boundary supports WebSerial in production and deterministic simulation in tests.
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

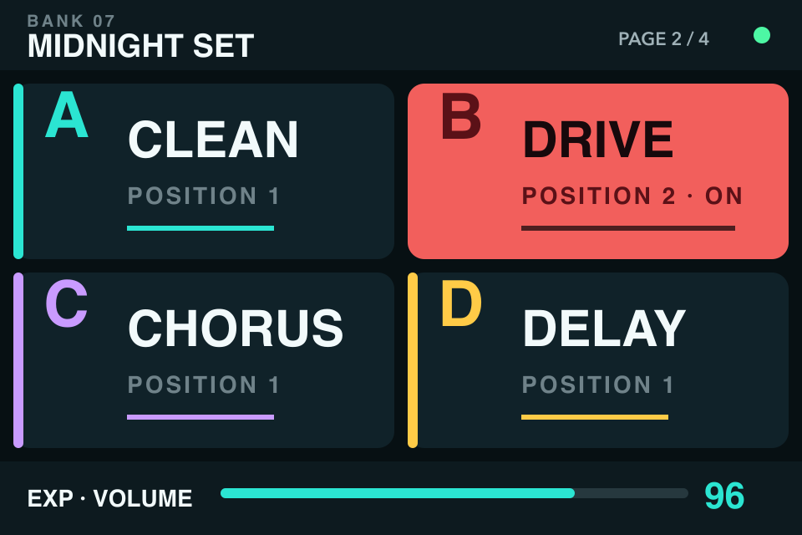
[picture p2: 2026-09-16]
docs/ui-concepts/01-chromatic-deck.png

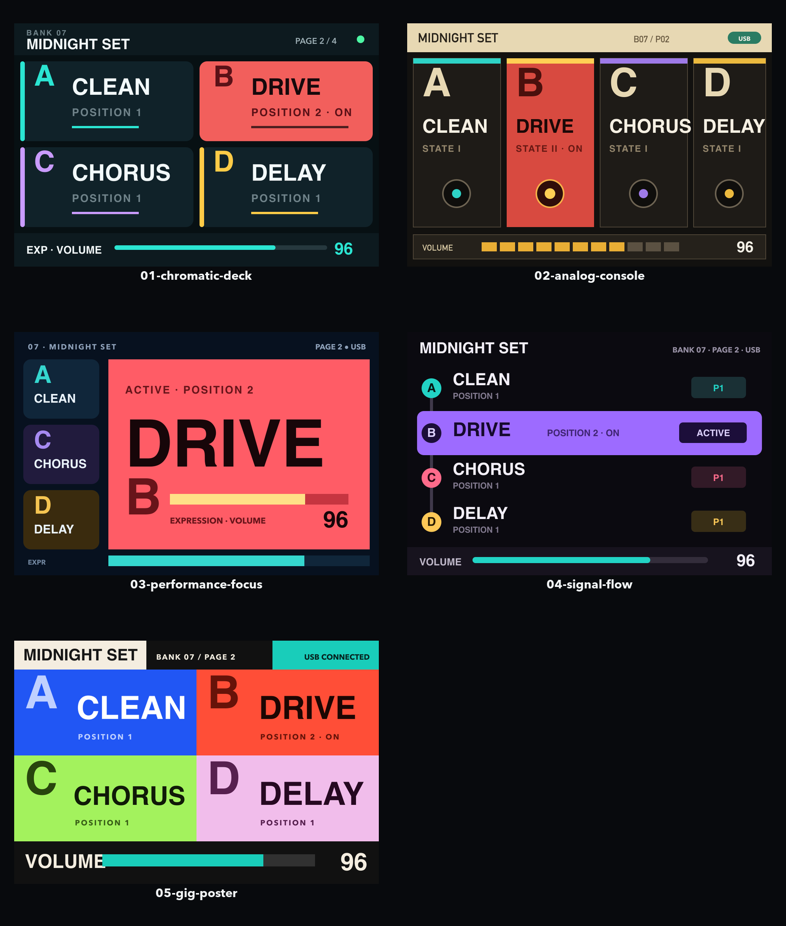
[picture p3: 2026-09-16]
docs/ui-concepts/all-five.png

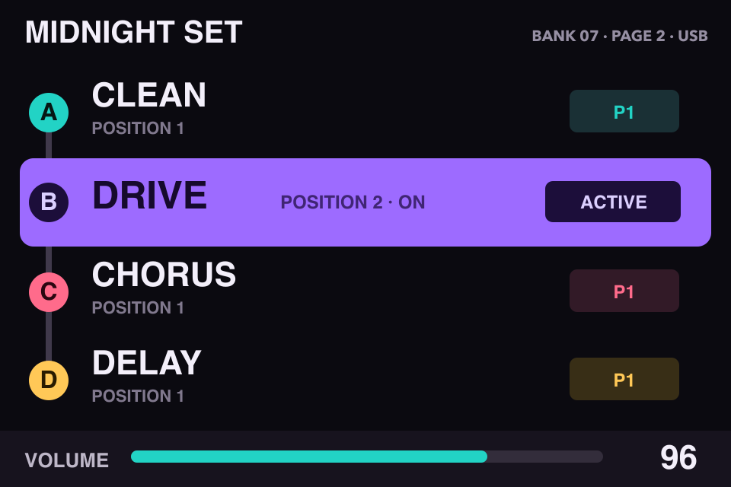
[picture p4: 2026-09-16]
docs/ui-concepts/04-signal-flow.png

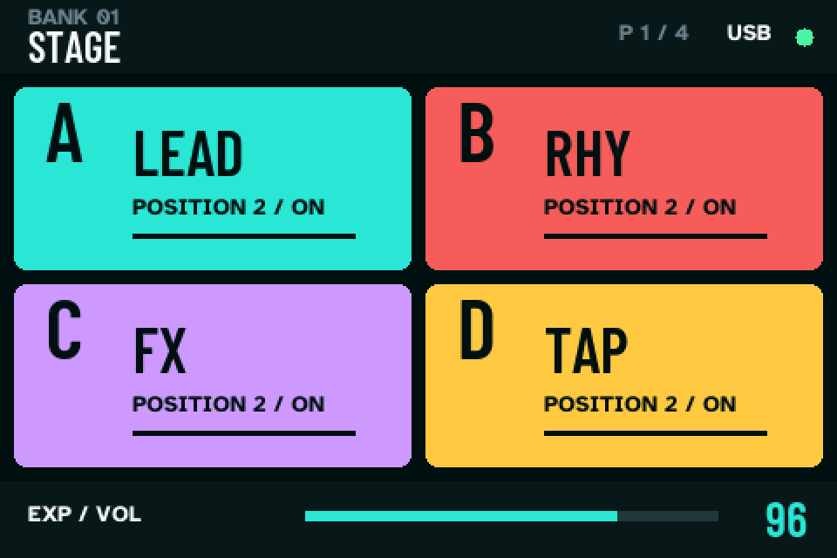
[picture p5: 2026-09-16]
docs/ui-concepts/implemented-chromatic-deck.png

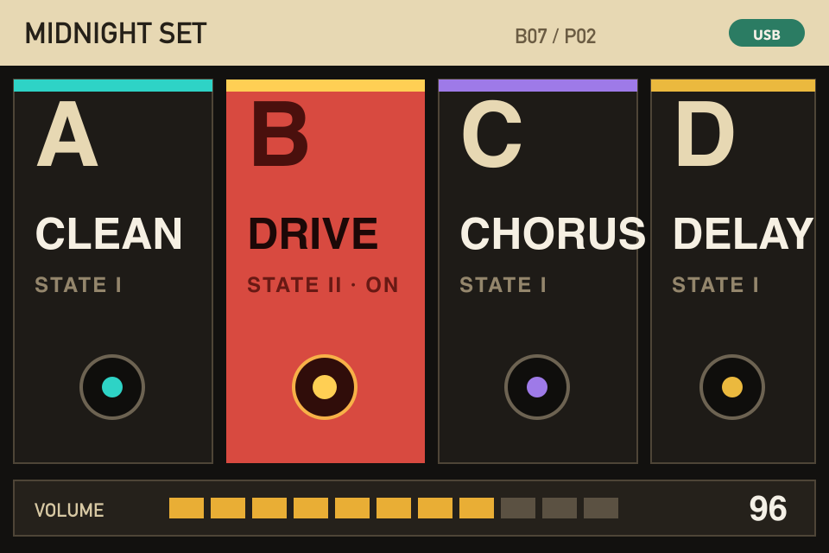
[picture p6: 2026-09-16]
docs/ui-concepts/02-analog-console.png

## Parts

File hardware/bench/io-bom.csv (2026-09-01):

ref | description | required_rating | manufacturer_part | status | notes
J1 | TRS Type-A MIDI OUT | 3.5mm panel jack | TBD | TO_SELECT | Confirm tip/ring mapping
J2 | dual dry-contact relay TRS | 3.5mm panel jack | TBD | TO_SELECT | Tip/contact1 ring/contact2
J3 | expression TRS | 6.35mm panel jack | TBD | TO_SELECT | 10–25k linear pedals
K1 | K2 | mechanical relay 5V coil and isolated contacts | TBD | TO_SELECT | Normally open
Q2 | Q3 | relay low-side drivers | logic-compatible | TBD | TO_SELECT | Default off
U2 | MIDI current-loop driver | 3.3V compliant | TBD | TO_SELECT | Standards review required
R/C | ADC protection and RC filter | 3.3V logic | TBD | TO_SELECT | ESD and input limit

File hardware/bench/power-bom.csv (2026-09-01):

ref | description | required_rating | manufacturer_part | status | notes
F1 | resettable input fuse | >=500mA hold at 9V | TBD | TO_SELECT | Select after load measurement
Q1 | reverse-polarity P-MOSFET | >=20V | >=2A | TBD | TO_SELECT | Verify body-diode orientation
TVS1 | transient suppressor | 12V standoff | TBD | TO_SELECT | Clamp raw input
U1 | 5V buck regulator | 5V output and Pico load | TBD | TO_SELECT | Follow datasheet layout
D1 | USB ideal-diode/reverse-current stage | USB VBUS isolation | TBD | TO_SELECT | No backfeed

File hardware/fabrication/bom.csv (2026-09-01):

ref | description | manufacturer_part | status
TBD | Production BOM is blocked on measured schematic/footprint review | TBD | PENDING

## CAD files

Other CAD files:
hardware/mechanical/front-panel.dxf
hardware/mechanical/rear-panel.dxf

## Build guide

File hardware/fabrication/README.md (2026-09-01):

# Fabrication package

The production Gerbers, drills, BOM, and placement files are intentionally not
generated yet: the current PCB is an unrouted outline placeholder and has not
passed ERC/DRC or independent footprint review. Once the schematic and board
are released, generate files with the KiCad CLI from the repository root:

```bash
kicad-cli sch erc hardware/midi-pedal.kicad_sch --exit-code-violations
kicad-cli pcb drc hardware/midi-pedal.kicad_pcb --exit-code-violations
kicad-cli pcb gerbers -o hardware/fabrication/gerbers/ hardware/midi-pedal.kicad_pcb
kicad-cli pcb drill -o hardware/fabrication/drill/ hardware/midi-pedal.kicad_pcb
kicad-cli sch export bom hardware/midi-pedal.kicad_sch -o hardware/fabrication/bom.csv
kicad-cli pcb export pos --format csv -o hardware/fabrication/positions.csv hardware/midi-pedal.kicad_pcb
```

Record the KiCad version, board revision, command output, and SHA-256 hashes
in this file before handing files to a fabricator. Empty output directories in
this WIP revision are deliberate.

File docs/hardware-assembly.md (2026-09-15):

# Hardware assembly (reference build)

This guide is for the measured reference carrier and is intentionally marked
WIP. Do not drill an enclosure or order a PCB from the current placeholder
outline. Complete the mechanical measurement CSV, schematic review, ERC/DRC,
and first-article checklist first.

## Parts and orientation

- Keep the illustrated [`Pico 2 wiring pinout`](../hardware/pico2-pinout.svg)
  beside the build. It labels both GPIO numbers and physical header pins.
- Socket a non-wireless Raspberry Pi Pico 2 so its USB connector remains
  accessible through the enclosure.
- Mount the ST7796S above the four normally-open footswitches in landscape
  orientation. Header order is `GND,VCC,SCL,SDA,RST,DC,CS,BL,SDA-0`; BL is
  always on and SDA-0/SDO is not connected.
- Wire switches A/B top row and C/D bottom row. Use the firmware pin map rather
  than assuming connector order.
- Use one 3.5 mm TRS Type-A MIDI OUT jack and one 3.5 mm TRS relay jack. Relay
  tip/contact 1 and ring/contact 2 switch independently to sleeve.
- Use one 6.35 mm TRS expression jack for voltage-divider pedals only. Ring is
  protected 3V3, tip is the ADC wiper, and sleeve is ground.
- Use a center-negative 9 V DC jack. Confirm polarity with a meter before
  plugging in; USB and 9 V source handover must not backfeed either source.

## Assembly order

1. Measure every panel part and update `hardware/mechanical/measured-components.csv`.
2. Print `hardware/mechanical/drill-template.svg` at 100% and test a paper/acrylic
   mock-up with real plugs, washers, nuts, and shoe clearance.
3. Populate and inspect the carrier unpowered; verify relay contacts are open,
   protection orientation, display VCC selection, and connector labels.
4. Fit the socketed Pico, display, jacks, and switches. Add strain relief and
   keep all unsleeved conductors away from the aluminum enclosure.
5. Power from a current-limited bench supply in the sequence in
   `hardware/validation/power-bench.md`, then run the firmware checks.

## Disassembly and safety

Disconnect USB and 9 V before opening the enclosure. Never connect a relay
contact to an amplifier switching voltage until an independent isolation review
has approved that use. Relay outputs are dry contacts, not logic outputs. Do
not change the display supply selector while powered.

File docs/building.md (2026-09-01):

# Building

The project has two build surfaces: native contract tests (always available)
and the Pico 2 firmware (requires the Arm compiler and the pinned Pico SDK).
The browser editor is a separate static Vite package. The commands below are
the source of truth for CI and are intended for Linux, macOS, and Windows
(PowerShell or Git Bash).

## Prerequisites

- Git 2.40 or newer, with submodule support
- Node.js 24 LTS and Corepack
- pnpm 10.15.0
- CMake 3.25 or newer and Ninja
- Arm GNU Toolchain (`arm-none-eabi-gcc`, `arm-none-eabi-g++`, `arm-none-eabi-newlib`) for firmware

The Pico SDK is pinned as `third_party/pico-sdk` at 2.2.0; do not replace it
with an unpinned system copy when reproducing a release. On Debian/Ubuntu,
the common host packages are:

```bash
sudo apt-get install cmake ninja-build gcc-arm-none-eabi libstdc++-arm-none-eabi-dev libstdc++-arm-none-eabi-newlib libnewlib-arm-none-eabi
```

On macOS install the equivalent packages with Homebrew. On Windows, install
the Arm GNU Toolchain and CMake/Ninja, then put their `bin` directories on
`PATH`. Verify the tools before continuing:

```bash
node --version          # v24.x
corepack enable
corepack prepare pnpm@10.15.0 --activate
pnpm --version          # 10.15.0
cmake --version
ninja --version
arm-none-eabi-gcc --version
```

## Clone and install

```bash
git clone --recurse-submodules git@github.com:balazsbencs/midi-pedal.git
cd midi-pedal
git submodule update --init --recursive
corepack enable
pnpm install --frozen-lockfile
```

## Native checks

```bash
pnpm check:toolchain
pnpm --filter @midi-pedal/protocol fixtures
git diff --exit-code protocol/fixtures
cmake --preset host-debug
cmake --build --preset host-debug
ctest --preset host-debug --output-on-failure
```

`pnpm test:ts` runs every workspace TypeScript test and `pnpm test:cpp` runs
the commands above. `pnpm check` combines the toolchain, TypeScript, and C++
checks. Native build output is under `build/host-debug/` and is not part of a
release.

## Pico 2 firmware

Configure and build the release target from a clean checkout:

```bash
cmake --preset pico2-release
cmake --build --preset pico2-release
```

The release outputs are:

```text
build/pico2-release/firmware/midi_pedal.uf2  # BOOTSEL drag-and-drop image
build/pico2-release/firmware/midi_pedal.elf  # debugger image
build/pico2-release/firmware/midi_pedal.hex  # probe/programmer image
build/pico2-release/firmware/midi_pedal.elf.map
```

The linker script keeps firmware below the 2 MiB configuration boundary. To
inspect the image before flashing:

```bash
arm-none-eabi-size build/pico2-release/firmware/midi_pedal.elf
stat -c '%s bytes' build/pico2-release/firmware/midi_pedal.bin   # Linux
```

Use `Get-Item ... .Length` for the equivalent PowerShell size check. Follow
[flashing.md](flashing.md) for BOOTSEL, picotool, debug-probe, and recovery
procedures. The checked-in factory image can be regenerated with:

```bash
pnpm factory:empty
git diff --exit-code firmware/defaults/factory-empty.bin
```

## Editor package

Once the editor package is present, build and test the static site with:

```bash
pnpm --filter @midi-pedal/editor typecheck
pnpm --filter @midi-pedal/editor test
pnpm --filter @midi-pedal/editor build
```

The deployable files are in `editor/dist/`; no server-side runtime is
required. See [editor-hosting.md](editor-hosting.md) for HTTPS/WebSerial
requirements.

## Reproducibility notes

- Do not commit `build/`, `editor/dist/`, or dependency caches.
- Keep `pnpm-lock.yaml` and the Pico SDK submodule pointer in commits that
  change tool versions.
- A physical display, MIDI monitor, relays, and expression pedal are required
  for the electrical checks in `hardware/validation/`; native tests cannot
  prove those measurements.

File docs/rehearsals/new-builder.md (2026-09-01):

# New-builder rehearsal

Status: **not yet performed on a clean external machine**. The repository is a
work in progress and the current hardware artifacts explicitly block a
fabrication/release claim until measured parts and ERC/DRC evidence exist.

Planned rehearsal:

1. Clone with submodules using only the README links.
2. Run native checks and build the Pico 2 UF2.
3. Follow flashing and first-power instructions with a current-limited supply.
4. Host `editor/dist/` over HTTPS, connect a pedal, import/export JSON, and sync.
5. Record every ambiguity, command/version, time, and resulting evidence here.

Reviewer/date: __________________

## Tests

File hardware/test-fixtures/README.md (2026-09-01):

# HIL fixture contract

The fixture must expose isolated TRS MIDI capture, USB-MIDI capture, relay
continuity probes, expression-pedal sweep input, a controllable power source,
and a display timing/photo trigger. Every manual operation starts unpowered;
the operator records instrument, range, probe points, board revision, and raw
evidence path. A simulated run cannot qualify relay, power, or enclosure safety.

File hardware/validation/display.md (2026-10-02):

# Display validation

The renderer geometry and RGB565 output are covered by native tests and the
committed golden rasters in `firmware/tests/golden/display/`. Physical timing
and panel readability still require a connected ST7796S module.

| Check | Procedure | Evidence | Status |
|---|---|---|---|
| Initialization | Flash the Pico 2, observe reset/sleep-out/display-on sequence, and confirm 480×320 landscape orientation | Photo and logic-analyzer trace | Pending hardware |
| Dirty update | Capture a switch press and measure first visible pixel change | Timestamped capture; target under 100 ms | Pending hardware |
| Full screen | Capture factory-empty, toggle position 1/2, unavailable expression, and recoverable-error states | Photos linked to build/revision | Pending hardware |
| Backlight/SDO wiring | Confirm backlight is hardwired on and SDO is intentionally not connected | Wiring photo | Pending hardware |

## Firmware update performance

The current panel workaround requires a full 480×320 address window at the
hardware-tested 8 MHz SPI request. Partial vertical windows are unreliable on
this module. Each refresh therefore still sends 307,200 bytes; its ideal wire
time is approximately 307 ms, before command and scheduling overhead. The
original PR's 93–96% SPI traffic reduction does not apply to this workaround.

DMA sends four scanlines per chunk while the control loop continues processing
switches, expression, MIDI, USB, and watchdog work. `service()` returns while
DMA or SPI is busy; it retains CS until the final bit of the complete frame has
left the wire. A 3,840-byte staging buffer keeps queued pixels stable when
`present()` updates the framebuffer during a transfer. Updates received during
transmission remain pending for a subsequent full refresh.

The renderer compares old/new RGB565 tiles and copies only changed bounds into
the framebuffer. A label-only `RHYTHM` → `LEAD` change copies 2,470 pixels instead
of the 23,940 pixels in a complete deck tile (89.7% fewer copied pixels). This
is a framebuffer-copy measurement, not a wire-traffic or visible-latency claim.
Press and toggle changes intentionally fill the deck tile and require larger
updates. The new deck geometry, fonts, colors, press feedback, and committed
golden rasters are preserved.

The renderer uses three 4 KiB scratch tiles (8 KiB more than the original
renderer). Together with the DMA staging buffer this adds 11.75 KiB of bounded
RAM to the framebuffer-based implementation.

Native tests compare incremental output with fresh renders across 80 state
transitions, including press/release, shorter labels, expression changes,
diagnostics, accent changes, and invalidation. Device-branch SDK-fake tests
verify non-blocking DMA service, staging-buffer lifetime, final SPI drain,
complete frame transfers, subsequent refreshes for intervening updates, and
rejection of incomplete/out-of-bounds writes.

On hardware, measure accepted-event-to-first-pixel and accepted-event-to-last-pixel
latency while expression and USB MIDI are active; check TRS/USB MIDI latency as
well. Attach traces/photos above before claiming physical timing qualification.

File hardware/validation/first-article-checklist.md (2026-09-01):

# First-article checklist

Record the board revision and operator for each item. A blank or unchecked item
blocks release.

- [ ] Unpowered visual inspection and BOM/orientation match
- [ ] Resistance-to-ground and short check on raw/protected/5V/VSYS/3V3
- [ ] Both relay contacts open before Pico/display installation
- [ ] Display VCC selector matches the measured module rating
- [ ] Pico socket, USB, SWD, and panel connector access
- [ ] Current-limited staged power-up
- [ ] USB CDC and USB-MIDI enumeration
- [ ] TRS MIDI PC/CC capture and per-message routing
- [ ] Four switches, all chords, repeat, long/double gestures
- [ ] Expression calibration, sweep, disconnect, and invalid span
- [ ] Relay open/close/toggle and reset/power-loss fail-open
- [ ] Display snapshots and dirty-update timing
- [ ] USB-only, 9 V-only, both-source, and source-removal handover
- [ ] 30-minute thermal observation

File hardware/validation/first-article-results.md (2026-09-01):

# First-article results

Status: **pending hardware**.

| Field | Value |
|---|---|
| Board revision | |
| Pico 2 / display serial | |
| Firmware commit | |
| Editor commit | |
| Operator/date | |
| Evidence directory | |
| Decision | NOT QUALIFIED |

Do not change `Decision` to qualified without attached measurements for every
item in `first-article-checklist.md` and clean, reviewed ERC/DRC output.

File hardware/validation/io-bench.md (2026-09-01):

# I/O bench validation

Status: **pending physical bench work**. Test the actual modules and the
firmware commit recorded beside each capture.

| Interface | Required evidence | Status |
|---|---|---|
| MIDI OUT | 31,250 baud bytes for PC and CC, Type-A polarity/current-loop capture | Pending |
| Relay 1/2 | continuity OPEN/CLOSE/TOGGLE, isolation, reset/BOOTSEL/brownout/power-loss | Pending |
| Expression | 10 kΩ and 25 kΩ sweeps, unplug/replug, ADC/noise CSV | Pending |
| Switches | pull-up level, bounce, all chord timing | Pending |
| ST7796S | exact 9-pin order, 3.3 V logic, VCC option only when rated | Pending |

Attach instrument model, range, date, board revision, and raw capture path;
do not summarize an unmeasured row as a pass.

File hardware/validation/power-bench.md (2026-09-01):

# Power bench validation

Status: **pending physical bench work**. The table is the required evidence
record; blank values are not passes.

| Mode | VSYS idle | VSYS full load | USB reverse current | Reset observed | Evidence |
|---|---:|---:|---:|---|---|
| USB only | | | | | |
| 9 V only | | | | | |
| USB + 9 V | | | | | |
| Remove USB while 9 V remains | | | | | |
| Remove 9 V while USB remains | | | | | |

Procedure: current-limit the supply to 50 mA, fit no Pico for polarity/short
tests, sweep the protected input to 12 V, verify reverse 9 V is blocked, then
fit the Pico and repeat each handover. Record temperatures after 30 minutes.
Acceptance is VSYS within Pico limits, no reset on handover, no measurable
backfeed at 1 mA resolution, and no component over 30 °C rise.

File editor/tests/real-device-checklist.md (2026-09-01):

# Real-device browser checklist

Record browser version, OS, firmware commit, editor commit, and device serial
before starting. Run the matrix in current stable desktop Chrome, Edge, and
Brave from an HTTPS deployment.

- [ ] Connect, grant WebSerial permission, read capabilities and active CRC.
- [ ] Edit a label and expression assignment; confirm local dirty status.
- [ ] Export JSON; import it back and confirm opaque metadata is retained.
- [ ] Sync a changed draft; observe BEGIN, WRITE, VERIFY, ACTIVATE, READBACK.
- [ ] Unplug USB during WRITE; reconnect and verify the previous CRC remains active.
- [ ] Complete a second sync and compare active CRC with the compiled image.
- [ ] Confirm USB-MIDI output and TRS output independently, then with BOTH routing.
- [ ] Switch Light/Dark mode, reload, and confirm the explicit choice persists.
- [ ] Resize to a laptop viewport and browser zoom 200%; confirm no required horizontal scroll.
- [ ] Use Factory empty reset only after exporting the desired JSON backup.

Attach screenshots, browser console output, and a USB/MIDI monitor capture for
any failure. A checklist entry without evidence is not a release qualification
pass.

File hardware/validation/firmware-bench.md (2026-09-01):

# Firmware bench validation

This log is intentionally a checklist until a physical Pico 2 and carrier are
available. Do not treat an unchecked row as a hardware pass.

| Check | Instrument/procedure | Evidence | Status |
|---|---|---|---|
| TRS MIDI timing | Logic analyzer on MIDI DIN output; 31,250 baud, 8-N-1; capture a press and compare the first byte timestamp | Attach capture and measured latency | Pending hardware |
| Relay 1/2 fail-open | Continuity meter while powering, resetting, holding BOOTSEL, watchdog resetting, and unplugging | Attach continuity notes/photos | Pending hardware |
| Expression ADC | Calibrated pedal at heel, toe, and unplugged; record ADC counts and emitted CC values | Attach CSV capture | Pending hardware |
| USB MIDI | Host enumerates CDC and MIDI interfaces; monitor one CC packet | Attach host/device capture | Pending hardware |

The native contract tests and the Pico 2 release build are automated checks;
they do not replace these electrical measurements. Relay contacts are designed
as normally open, and firmware also drives both outputs low before configuration
is read.

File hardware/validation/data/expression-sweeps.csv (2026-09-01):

timestamp | pedal_nominal_kohm | position | adc_raw | filtered_value | midi_value | connected | firmware_commit | evidence | status
 |  |  |  |  |  |  |  |  | PENDING

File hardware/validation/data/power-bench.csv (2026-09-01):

timestamp | mode | vin_v | usb_v | protected_v | reg_5v | vsys_v | current_ma | reverse_current_ma | temp_rise_c | reset | operator | evidence | status
 |  |  |  |  |  |  |  |  |  |  |  |  | PENDING

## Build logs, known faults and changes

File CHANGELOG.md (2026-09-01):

# Changelog

## Unreleased

- Added the shared configuration/image/frame contracts and golden fixtures.
- Added deterministic Pico 2 switch, action, expression, flash, USB, and
  ST7796S renderer foundations.
- Added the static Chromium editor with local drafts, themes, WebSerial
  synchronization, and a simulated device.
- Added measured-hardware placeholders, validation checklists, HIL reporting,
  and reproducible build/flash documentation.

The first public release remains blocked on measured carrier hardware, clean
ERC/DRC, and physical HIL evidence.

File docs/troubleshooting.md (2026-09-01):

# Troubleshooting

## No power or unexpectedly high current

Disconnect USB and 9 V immediately. With the Pico removed, verify the DC jack
is center-negative, inspect the fuse/TVS/reverse-polarity stage, and use a
current-limited supply. Do not bypass protection. Compare measured rails with
`hardware/validation/power-bench.md`; stop if any rail exceeds its documented
range.

## No USB interfaces or WebSerial says unavailable

Use a data-capable cable, reflash the UF2 through BOOTSEL, and try current
desktop Chrome/Edge/Brave on HTTPS (or localhost). A permission denial is
recoverable from **Connect pedal**; a busy port means close other serial
monitors. Safari, Firefox, mobile browsers, and insecure remote HTTP are not
supported.

## No TRS MIDI or USB-MIDI output

Confirm the selected preset has a PC/CC action, the channel/value are in range,
and the destination includes the output being monitored. Test one output at a
time, use a known Type-A cable, and capture at 31,250 baud. USB-MIDI can be
absent when no host is mounted; TRS output must remain independent. Power off
before changing jack wiring.

## Noisy, inverted, or absent expression

Use a voltage-divider TRS pedal in the 10–25 kΩ target range. Verify ring is
protected 3V3, tip is the wiper, and sleeve is ground. Recalibrate heel/toe,
check the minimum span (at least 410 ADC counts), and use the inversion setting
for mechanical direction. Unplugged or invalid input intentionally emits no
MIDI.

## Relay wrong or closed by default

Power off and use continuity mode. Both contacts must be open with no power,
during reset/BOOTSEL, and after a watchdog/brownout test. Verify relay TRS tip
and ring identity and never connect external amplifier voltages until an
isolation review approves them.

## Blank or wrong-color display

Power off and check the exact header order
`GND,VCC,SCL,SDA,RST,DC,CS,BL,SDA-0`. Logic is 3.3 V, BL is always on, and
SDA-0/SDO is intentionally unconnected. Confirm the module's VCC rating before
using the carrier supply selector. Compare the renderer golden state before
suspecting configuration.

## Upload failed or schema incompatible

Do not unplug repeatedly while powered. The atomic protocol leaves the prior
validated image active after a bad chunk, verify failure, or disconnect. Export
the local JSON, reconnect, check protocol/schema compatibility, and retry. Use
Factory empty reset only after making a backup.

## USB/9 V source handover resets the pedal

Disconnect both sources, stop using the board, and inspect the isolation stage.
Record which source was removed, rail measurements, current, and revision in
`hardware/validation/power-bench.md`. This is a hardware safety issue, not an
editor setting.

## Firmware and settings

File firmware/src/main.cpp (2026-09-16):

#ifdef PICO_ON_DEVICE

#include <cstddef>
#include <cstdint>
#include <span>

#include "pico/stdlib.h"

#include "app/controller.hpp"
#include "app/controller_protocol_service.hpp"
#include "app/pedal_runtime.hpp"
#include "board/pico2_pins.hpp"
#include "core/config_store.hpp"
#include "hal/pico_expression_adc.hpp"
#include "hal/pico_flash_port.hpp"
#include "hal/pico_relays.hpp"
#include "hal/pico_switches.hpp"
#include "hal/pico_uart_midi.hpp"
#include "hal/pico_watchdog.hpp"
#include "display/st7796s.hpp"
#include "usb/pico_usb.hpp"
#include "usb/protocol_dispatcher.hpp"

extern "C" {
extern const std::uint8_t _binary_firmware_defaults_factory_empty_bin_start[];
extern const std::uint8_t _binary_firmware_defaults_factory_empty_bin_end[];
}

namespace {
class PicoPorts final : public midi::ControllerPorts {
 public:
  PicoPorts() { relays_.initialize(); }

  void attach_config(midi::ConfigStore& config) { config_ = &config; }

  void relay_set(std::uint8_t contact, bool closed) override {
    relays_.set(contact, closed);
  }

  bool read_active_config() override { return config_ != nullptr && config_->active_info().has_value(); }
  void show_boot_status() override {}

  midi::PicoSwitches& switches() { return switches_; }
  midi::PicoUartMidi& midi() { return midi_; }
  midi::PicoExpressionAdc& expression() { return expression_; }
  midi::PicoRelays& relays() { return relays_; }

 private:
  midi::ConfigStore* config_{};
  midi::PicoRelays relays_;
  midi::PicoSwitches switches_;
  midi::PicoUartMidi midi_;
  midi::PicoExpressionAdc expression_;
};

class PicoConfigSource final : public midi::RuntimeConfigSource {
 public:
  explicit PicoConfigSource(midi::ConfigStore& store) : store_(store) {}

  [[nodiscard]] midi::RuntimeConfigSnapshot status() const override {
    const auto info = store_.active_info();
    return info.has_value() ? midi::RuntimeConfigSnapshot{true, info->sequence, info->bank_count}
                             : midi::RuntimeConfigSnapshot{};
  }

  [[nodiscard]] bool load_bank(std::uint8_t index, midi::BankConfig& output) const override {
    return store_.load_bank(index, output);
  }

 private:
  midi::ConfigStore& store_;
};

class PicoSwitchInput final : public midi::RuntimeSwitchSource {
 public:
  explicit PicoSwitchInput(const midi::PicoSwitches& switches) : switches_(switches) {}

  [[nodiscard]] std::uint8_t read_mask() const override { return switches_.read_mask(); }

 private:
  const midi::PicoSwitches& switches_;
};

class PicoExpressionInput final : public midi::ExpressionSampleInput, public midi::RuntimeExpressionSource {
 public:
  explicit PicoExpressionInput(const midi::PicoExpressionAdc& adc) : adc_(adc) {}

  [[nodiscard]] std::uint16_t read_adc() const override { return adc_.read(); }

 private:
  const midi::PicoExpressionAdc& adc_;
};
}  // namespace

int main() {
  stdio_init_all();
  midi::PicoFlashPort flash;
  PicoPorts ports;
  midi::PicoWatchdog watchdog;
  const auto watchdog_reset = watchdog.initialize();
  midi::ConfigStore config(flash);
  ports.attach_config(config);
  ports.switches().initialize();
  ports.midi().initialize();
  ports.expression().initialize();
  midi::display::St7796sDisplay display;
  display.initialize();
  midi::Controller controller(ports);
  controller.initialize();

  PicoExpressionInput expression_input(ports.expression());
  midi::ExpressionProcessor expression(config.expression_calibration());
  const auto factory_start = reinterpret_cast<std::uintptr_t>(_binary_firmware_defaults_factory_empty_bin_start);
  const auto factory_end = reinterpret_cast<std::uintptr_t>(_binary_firmware_defaults_factory_empty_bin_end);
  const auto factory_size = factory_end >= factory_start ? static_cast<std::size_t>(factory_end - factory_start) : 0;
  const auto factory_image = std::span<const std::byte>(
      reinterpret_cast<const std::byte*>(factory_start), factory_size);
  midi::ControllerProtocolService protocol(config, expression_input, expression, factory_image);
  midi::usb::PicoUsbDeviceApi usb_api;
  midi::usb::PicoUsbPort usb(usb_api);
  (void)usb.initialize();
  midi::usb::ProtocolDispatcher dispatcher(protocol, usb);
  PicoConfigSource config_source(config);
  PicoSwitchInput switch_input(ports.switches());
  midi::usb::UsbTransport usb_transport(usb);
  midi::PedalRuntime runtime(config_source, switch_input, expression_input, ports.midi(), ports.relays(),
                             usb_transport, usb, display, expression, watchdog_reset);
  protocol.set_live_action_state(&runtime);
  (void)runtime.initialize();
  while (true) {
    runtime.tick(to_ms_since_boot(get_absolute_time()));
    usb.service(dispatcher);
    runtime.finish_control_phase();
    ports.midi().service();
    watchdog.feed();
    display.service();
    tight_loop_contents();
  }
}

#endif

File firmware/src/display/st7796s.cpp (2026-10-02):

#include "st7796s.hpp"

#include <algorithm>
#include <array>

#include "../board/pico2_pins.hpp"

#ifdef PICO_ON_DEVICE
#include "hardware/dma.h"
#include "hardware/gpio.h"
#include "hardware/spi.h"
#include "pico/stdlib.h"
#endif

namespace midi::display {
namespace {

#ifdef PICO_ON_DEVICE
constexpr std::size_t ScanlineBytes = ScreenWidth * 2;
alignas(4) std::array<std::uint8_t,
                      static_cast<std::size_t>(ScreenWidth) * ScreenHeight * 2>
    frame_bytes{};
#endif

}  // namespace

void St7796sDisplay::initialize() {
#ifdef PICO_ON_DEVICE
  gpio_init(board::DisplayCs);
  gpio_init(board::DisplayDc);
  gpio_init(board::DisplayReset);
  gpio_put(board::DisplayCs, 1);
  gpio_put(board::DisplayDc, 1);
  gpio_put(board::DisplayReset, 1);
  gpio_set_dir(board::DisplayCs, GPIO_OUT);
  gpio_set_dir(board::DisplayDc, GPIO_OUT);
  gpio_set_dir(board::DisplayReset, GPIO_OUT);

  spi_init(spi0, SpiFrequencyHz);
  spi_set_format(spi0, 8, SPI_CPOL_0, SPI_CPHA_0, SPI_MSB_FIRST);
  gpio_set_function(board::DisplaySck, GPIO_FUNC_SPI);
  gpio_set_function(board::DisplayMosi, GPIO_FUNC_SPI);

  sleep_ms(20);
  gpio_put(board::DisplayReset, 0);
  sleep_ms(120);
  gpio_put(board::DisplayReset, 1);
  sleep_ms(200);

  command(0x01);  // Software reset.
  sleep_ms(150);

  // ST7796S manufacturer sequence used by the known-good display test.
  command(0xF0, std::array<std::uint8_t, 1>{0xC3});
  command(0xF0, std::array<std::uint8_t, 1>{0x96});
  command(0xC5, std::array<std::uint8_t, 1>{0x1C});
  command(0x36, std::array<std::uint8_t, 1>{MadctlLandscape});
  command(0x3A, std::array<std::uint8_t, 1>{PixelFormatRgb565});
  command(0xB0, std::array<std::uint8_t, 1>{0x80});
  command(0xB4, std::array<std::uint8_t, 1>{0x00});
  command(0xB6, std::array<std::uint8_t, 3>{0x80, 0x02, 0x3B});
  command(0xB7, std::array<std::uint8_t, 1>{0xC6});
  command(0xF0, std::array<std::uint8_t, 1>{0x69});
  command(0xF0, std::array<std::uint8_t, 1>{0x3C});

  command(0x11);  // Sleep out.
  sleep_ms(150);
  command(0x13);  // Normal display mode.
  command(0x20);  // Display inversion off; this panel renders logical RGB565 directly.
  command(0x29);  // Display on.
  sleep_ms(150);
  dma_channel_ = dma_claim_unused_channel(true);
  initialized_ = true;
#else
  initialized_ = true;
#endif
}

void St7796sDisplay::command(
    std::uint8_t value, std::span<const std::uint8_t> parameters) {
#ifdef PICO_ON_DEVICE
  gpio_put(board::DisplayCs, 0);
  gpio_put(board::DisplayDc, 0);
  spi_write_blocking(spi0, &value, 1);
  if (!parameters.empty()) {
    gpio_put(board::DisplayDc, 1);
    spi_write_blocking(spi0, parameters.data(), parameters.size());
  }
  gpio_put(board::DisplayCs, 1);
#else
  (void)value;
  (void)parameters;
#endif
}

void St7796sDisplay::set_window(Rect rect) {
#ifdef PICO_ON_DEVICE
  const auto x1 = static_cast<std::uint16_t>(rect.x + rect.width - 1);
  const auto y1 = static_cast<std::uint16_t>(rect.y + rect.height - 1);
  const std::array<std::uint8_t, 4> columns{
      static_cast<std::uint8_t>(rect.x >> 8), static_cast<std::uint8_t>(rect.x),
      static_cast<std::uint8_t>(x1 >> 8), static_cast<std::uint8_t>(x1)};
  const std::array<std::uint8_t, 4> rows{
      static_cast<std::uint8_t>(rect.y >> 8), static_cast<std::uint8_t>(rect.y),
      static_cast<std::uint8_t>(y1 >> 8), static_cast<std::uint8_t>(y1)};
  command(0x2A, columns);
  command(0x2B, rows);
#else
  (void)rect;
#endif
}

void St7796sDisplay::present(const LiveView& view) {
  if (!initialized_) return;
  renderer_.render(view);
}

void St7796sDisplay::write(Rect rect, std::span<const std::uint16_t> pixels) {
  if (!initialized_ || rect.width == 0 || rect.height == 0) return;
  if (rect.x >= ScreenWidth || rect.y >= ScreenHeight ||
      rect.width > ScreenWidth - rect.x ||
      rect.height > ScreenHeight - rect.y) {
    return;
  }
  const auto expected = static_cast<std::size_t>(rect.width) * rect.height;
  if (pixels.size() < expected) return;
#ifdef PICO_ON_DEVICE
  for (std::uint16_t row = 0; row < rect.height; ++row) {
    for (std::uint16_t column = 0; column < rect.width; ++column) {
      const auto source = static_cast<std::size_t>(row) * rect.width + column;
      const auto destination =
          (static_cast<std::size_t>(rect.y + row) * ScreenWidth + rect.x +
           column) *
          2;
      frame_bytes[destination] =
          static_cast<std::uint8_t>(pixels[source] >> 8);
      frame_bytes[destination + 1] =
          static_cast<std::uint8_t>(pixels[source]);
    }
  }
  mark_dirty(rect);
#else
  (void)pixels;
#endif
}

void St7796sDisplay::mark_dirty(Rect rect) {
  (void)rect;
  // This module handles a full 480x320 window reliably, but ignores or
  // misapplies partial vertical windows. Keep the proven full-screen address
  // window while service() spreads its transfer over short control-loop steps.
  pending_rect_ = {0, 0, ScreenWidth, ScreenHeight};
  dirty_pending_ = true;
}

void St7796sDisplay::begin_transfer() {
#ifdef PICO_ON_DEVICE
  if (!dirty_pending_ || transfer_active_) return;
  transfer_rect_ = pending_rect_;
  dirty_pending_ = false;
  transfer_row_ = 0;
  set_window(transfer_rect_);
  const std::uint8_t memory_write = 0x2C;
  gpio_put(board::DisplayCs, 0);
  gpio_put(board::DisplayDc, 0);
  spi_write_blocking(spi0, &memory_write, 1);
  gpio_put(board::DisplayDc, 1);
  transfer_active_ = true;
#endif
}

void St7796sDisplay::service() {
#ifdef PICO_ON_DEVICE
  if (!initialized_) return;
  if (chunk_pending_) {
    // DMA completion only fills the SPI FIFO. Retain CS and the staging
    // buffer until the last bit has left the shift register.
    if (dma_channel_is_busy(dma_channel_) || spi_is_busy(spi0)) return;
    chunk_pending_ = false;
    transfer_row_ = static_cast<std::uint16_t>(transfer_row_ + chunk_rows_);
    if (transfer_row_ == transfer_rect_.height) {
      gpio_put(board::DisplayCs, 1);
      transfer_active_ = false;
      return;
    }
  }
  if (!transfer_active_) begin_transfer();
  if (!transfer_active_) return;

  chunk_rows_ = std::min<std::uint16_t>(
      RowsPerService, transfer_rect_.height - transfer_row_);
  const auto byte_count = static_cast<std::size_t>(chunk_rows_) * ScanlineBytes;
  const auto offset = static_cast<std::size_t>(transfer_row_) * ScanlineBytes;
  // present() may update the framebuffer while DMA runs. Copy this chunk
  // into an owned staging buffer so pixels already queued remain stable.
  std::copy_n(frame_bytes.data() + offset, byte_count, transfer_bytes_.data());
  auto config = dma_channel_get_default_config(dma_channel_);
  channel_config_set_transfer_data_size(&config, DMA_SIZE_8);
  channel_config_set_dreq(&config, spi_get_dreq(spi0, true));
  dma_channel_configure(dma_channel_, &config, &spi0_hw->dr,
                        transfer_bytes_.data(), byte_count, true);
  chunk_pending_ = true;
#endif
}

}  // namespace midi::display

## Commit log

2026-09-01 feat(protocol): encode deterministic device images
2026-09-01 feat(protocol): define USB configuration frames
2026-09-01 build(firmware): boot Pico 2 into a safe controller shell
2026-09-01 feat(firmware): recognize switch gestures and navigation chords
2026-09-01 feat(firmware): process calibrated expression input
2026-09-01 feat(firmware): drive Pico 2 pedal interfaces
2026-09-01 feat(editor): wire workspace shell
2026-09-01 docs(hardware): capture measured carrier design inputs
    [bom.csv, expression-sweeps.csv, front-panel.dxf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]
2026-09-01 feat(firmware): connect Pico configuration protocol runtime
2026-09-01 fix(firmware): compile device HAL for Pico builds
2026-09-01 feat(firmware): persist calibration and gate live uploads
2026-09-01 fix(firmware): retain calibration across journal cuts
2026-09-01 fix(firmware): bound upload flash work and latch busy phase
    [main.cpp]
2026-09-01 ci: install ARM C++ runtime headers
2026-09-01 ci: install ARM C++ newlib library
2026-09-01 ci: make ARM package install noninteractive
2026-09-15 docs: add Pico 2 wiring infographic
2026-09-15 docs: align pinout callouts with Pico headers
